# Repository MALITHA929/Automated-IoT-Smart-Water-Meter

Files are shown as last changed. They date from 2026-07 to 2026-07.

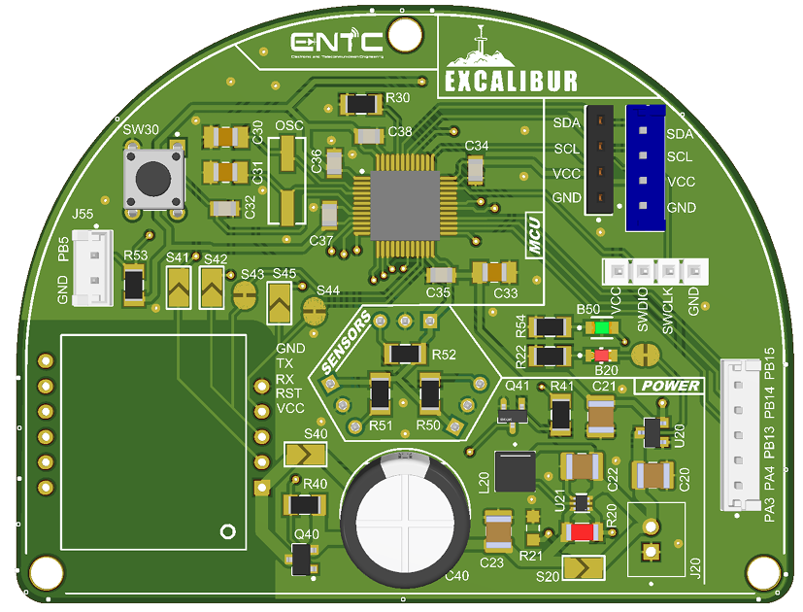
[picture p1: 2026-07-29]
PCB_Image.png

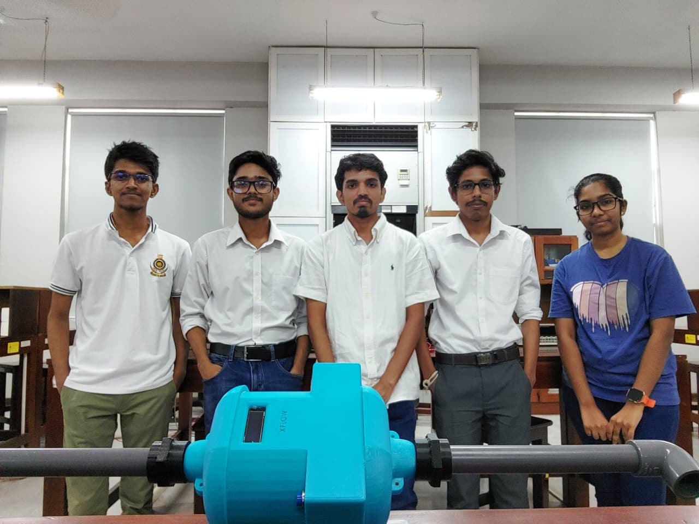
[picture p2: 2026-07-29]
Team_Photo.jpeg

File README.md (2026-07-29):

# 💧 Automated IoT Smart Water Meter

An IoT-enabled smart water metering system designed to modernize residential and utility-scale water management through real-time monitoring, automated billing, leak detection, and cloud-based data analytics. The system integrates a custom embedded hardware platform, GSM communication, cloud infrastructure, and web dashboards to improve billing accuracy, reduce Non-Revenue Water (NRW), and support the digital transformation of Sri Lanka's water distribution network.

---

# 📌 Overview

Traditional mechanical water meters rely on manual meter reading, making them susceptible to inaccurate billing, delayed data collection, water leakage, and high operational costs. Additionally, consumers and water authorities have limited visibility into real-time water consumption, making it difficult to identify leaks and abnormal usage patterns.

The **Automated IoT Smart Water Meter** addresses these challenges by combining low-power embedded hardware, wireless communication, cloud computing, and intuitive web applications into a complete smart metering ecosystem.

The system continuously measures water flow, securely transmits data to the cloud, automatically calculates water consumption, generates billing information, and provides real-time monitoring for both consumers and water utility providers.

---

# 🎯 Objectives

- Develop a low-cost IoT-enabled smart water meter
- Enable real-time water consumption monitoring
- Eliminate manual meter reading
- Automate water billing
- Reduce Non-Revenue Water (NRW)
- Detect leaks and abnormal consumption
- Provide centralized cloud-based monitoring
- Support future smart city infrastructure

---

# 🚰 Problem Statement

Sri Lanka continues to experience significant **Non-Revenue Water (NRW)** losses due to:

- Water leakage
- Manual meter reading
- Meter tampering
- Inaccurate billing
- Delayed data collection
- Lack of real-time monitoring
- High maintenance costs
- Limited consumer visibility

The proposed solution digitizes the entire water metering process while improving operational efficiency for both consumers and water authorities.

---

# 💡 Solution

The proposed system combines:

- Custom Embedded Hardware
- STM32 Low-Power Microcontroller
- Hall-Effect Flow Sensor
- GSM Communication
- Cloud Database
- Administrator Dashboard
- Consumer Web Portal

The smart meter continuously measures water flow, processes consumption locally, transmits data through GSM, stores information securely in the cloud, and presents live analytics through dedicated web dashboards.

---

# ✨ Key Features

## 💧 Smart Water Meter

- Real-time flow measurement
- Cumulative water consumption calculation
- Automated billing
- Leak detection
- Tamper-resistant monitoring
- Low-power operation
- Long battery life
- Remote monitoring

---

## 🌐 Cloud Platform

- Secure cloud database
- Historical data storage
- Live synchronization
- Consumption analytics
- Automated notifications
- REST API integration

---

## 👨‍💼 WaterboardOS (Administrator Dashboard)

- Network-wide monitoring
- Customer management
- Revenue analytics
- Water consumption statistics
- Historical usage trends
- Centralized administration
- Utility monitoring

---

## 👤 AquaSync (Consumer Dashboard)

- Real-time water usage
- Estimated monthly bill
- Historical consumption graphs
- Leak notifications
- Account management
- Previous billing history
- Live synchronization status

---

# ⚙️ Hardware Architecture

## Embedded System

- STM32L071CBT6 (ARM Cortex-M0+)
- SIM800L GSM Module
- Hall-Effect Flow Sensor
- Li-SOCl₂ Battery
- OLED Display
- RTC Crystal
- Low-Power Design

---

## Power Management

- TPS61023 Buck-Boost Converter
- XC6206 3.3V LDO Regulator
- Battery Protection Circuit
- Ultra-Low Power Sleep Mode

---

## Communication

- GSM/GPRS Communication
- HTTP POST Data Transmission
- Cloud Synchronization
- REST API Integration

---

# 🖥️ Software Stack

### Embedded Software

- Embedded C
- STM32CubeIDE
- Low-Power Firmware
- Pulse Counting
- Flow Calculation
- GSM Communication

### Web Technologies

- HTML5
- CSS3
- JavaScript

### Cloud

- Supabase
- REST APIs
- Cloud Database

---

# 📐 PCB Design

The complete hardware platform was designed as a custom **2-layer PCB** using **Altium Designer**.

The PCB includes:

- Power Subsystem
- STM32 MCU Subsystem
- GSM Communication Circuit
- Sensor Interface
- OLED Interface
- SWD Programming Interface
- Expansion GPIO Header

---

# 🛠 Mechanical Design

A custom waterproof enclosure was designed using **SolidWorks** for outdoor deployment.

Features include:

- Waterproof enclosure
- Standard plumbing connectors
- Optimized 9-blade turbine
- Hall sensor mounting
- PCB isolation
- Future expansion support

---

# 🧠 System Workflow

```text
Water Flow
     │
     ▼
Hall-Effect Sensor
     │
     ▼
STM32L0 MCU
     │
Flow Calculation
     │
     ▼
SIM800L GSM Module
     │
     ▼
Cloud Database (Supabase)
     │
     ▼
 ┌───────────────┬────────────────┐
 ▼                               ▼
WaterboardOS               AquaSync
(Admin Dashboard)      (Consumer Dashboard)
```

---

# 🔒 Security

- Secure cloud storage
- Unique meter identification
- Timestamped records
- Role-based authentication
- Secure API communication
- Centralized data management

---

# 📈 Benefits

### Consumers

- Live water usage monitoring
- Accurate billing
- Leak notifications
- Consumption history
- Better water conservation

### Water Utilities

- Reduced Non-Revenue Water
- Automated billing
- Reduced operational costs
- Remote monitoring
- Better maintenance planning
- Revenue analytics

---

# 🚀 Future Improvements

- NB-IoT Connectivity
- LoRaWAN Support
- Remote Valve Control
- AI-Based Leak Prediction
- Smart City Integration
- Mobile Application
- Predictive Maintenance
- Enterprise Cloud Infrastructure

---

# 👥 Team Excalibur

- A.H.T.M. Weerakoon
- K.D. Manatunga
- H.D.J.D. Samaranayaka
- W.M.H. Wanigasundara
- H.W.D. Prabarshana

---

# 👨‍💻 My Contributions

- Mechanical enclosure design using **SolidWorks**
- Electronic component selection
- Hardware integration
- System assembly and soldering
- Prototype testing and validation
- Performance evaluation
- Debugging and hardware verification

---

# 🎓 Academic Project

**Course:** EN2160 – Electronic Design Realization

**Department:** Electronic and Telecommunication Engineering

**University:** University of Moratuwa

---

# 📜 License

This project was developed for academic and research purposes as part of the EN2160 – Electronic Design Realization module at the University of Moratuwa.

---

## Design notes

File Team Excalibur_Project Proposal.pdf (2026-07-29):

# Project Proposal

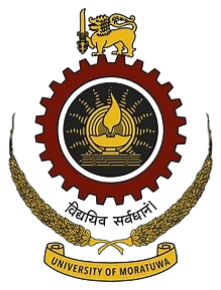
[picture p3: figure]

K.D.Manatunga | 230395T
H.W.D.Prabarshana | 230495B
H.D.J.D.Samaranayake | 230563H
W.M.H.Wanigasundara 230680M A.H.T.M Weerakoon 230689A

## EN-2160 : Engineering Design Realization

### Department of Electronic and Telecommunication Engineering University of Moratuwa

## 1 Problem Statement

### 1.1 Introduction

In Sri Lanka the main sources of water supply to public is provided through sources such as piped water, public taps, tube wells, protected wells, semi protected wells, rural water supply projects, bottled water Then in case of pipe water distribution the main body that is responsible for that is National Water Supply and Drainage Board(NWSDB). About 75% of urban population and about 40% of the rural population are supplied water through this distribution newtorks. Main resoviours for them are tube wells and surfae water resoviours( eg. lakes, rivers etc)
Currently, meters are placed at the households or more generally at the user end to monitor the amount of usage for management purposes such as billing.

### 1.2 Current difficulties

- Manual measurement taking
The main thing we observe here is that water meter monitoring is something that has the potential to move towards automated monitoring to improve the quality of service by minimizing the errors occur and minimizing the costs by reducing the human interactions.
- Real-time monitoring and accessing usage history
In the current system, there is a lack of accessability to realtime data and to see the usage history. The only method that is possible right now is to look it from the meter directly or get annual data from the bill.

## 2 Proposed Solution

### 2.1 Introduction

We thought through the problem and decided to introduce an integrated device with a smart meter and a smart ball-valve.

### 2.2 Functionality

Here, using our proposed device we intend to let user access real-tine water usage and to make it convenient to analyze past data by providing an application for better user experience. In addition to that from the side of the water board we can illuminate the necessity of checking the meters by visiting house holds.

### 2.3 Existing products

In the market we can find the smart meter and the ball valve separately only in the international market. If someone to import them that will cost a huge amount considering all the expenditures with taxes and all.

### 2.4 Stake-holders

Some of the stake-holders that we identified regarding our project are,

- House-holds
- Farmers
- Water-board

2

### Resources

### - https://www.statistics.gov.lk/Resource/en/Health/DemographicAndHealthSurveyReport-

### 2016-Chapter2.pdf

### - https://drive.google.com/file/d/1m3dZbix2ck5f2yChTXGhR04r8Bdc5cNK/view

3

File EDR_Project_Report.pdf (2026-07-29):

# Automated IoT Smart Water Meter

# Project Report

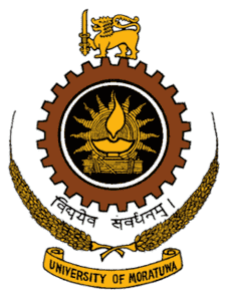
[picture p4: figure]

### TEAM EXCALIBUR

230395T | K.D. Manatunga
230563H | H.D.J.D.Samaranayaka
230680M | W.M.H.Wanigasundara
230689A | A.H.T.M.Weerakoon
230495B | H.W.D.Prabarshana

## EN2160 - Electronic Design Realization

### Department of Electronic and Telecommunication Engineering

### University of Moratuwa

### July 20, 2026

## CONTENTS

1 Problem Statement | 4
2 Objectives | 5
3 Survey & Market Validation | 6
4 Stakeholder and Needs Analysis | 10
5 Proposed Solution and Core Mechanism | 11
6 Hardware Architecture | 13
7 PCB Design and Schematic Architecture | 15
8 Software and Dashboard | 22
9 Mechanical Enclosure Design | 24
10 Cost Estimation and Production Scope | 26

Automated IoT Smart Water Meter | Project Report
11 Team Contributions | 28
12 Conclusion | 29

## 1 Problem Statement

Sri Lanka’s water supply network continues to experience significant Non-Revenue Water (NRW)

losses, resulting in substantial financial losses, operational inefficiencies, and reduced water

availability for consumers. NRW refers to treated water that is produced but not billed due

to physical leaks, unauthorized consumption, inaccurate metering, or administrative errors.

According to the National Water Supply and Drainage Board (NWSDB), the national NRW

level remains approximately 24.8, while the Auditor General’s report estimates losses of nearly

27. It is estimated that every 1% reduction in NRW could save approximately Rs. 790 million

annually, demonstrating the significant economic impact of improving water management.

Traditional mechanical water metering systems rely heavily on manual meter reading, mak-

ing the billing process susceptible to human error, estimated readings, delayed data collection,

and meter tampering. Furthermore, consumers and water authorities lack real-time visibility

into water consumption, preventing the early identification of abnormal usage patterns and

leakage.

Another major limitation of the current system is the absence of remote monitoring and

control capabilities. Water utilities must physically dispatch maintenance crews to inspect

meters, investigate leaks, or disconnect water supplies for maintenance or unpaid bills. This

process is time-consuming, labour-intensive, and increases operational costs.

Maintenance expenses associated with aging mechanical water meters also place a consider-

able financial burden on utilities. A JICA pilot study conducted in the Harispattuwa Division

reported an 8.37% defective meter rate and approximately Rs. 7.9 million spent on repairs,

illustrating the high maintenance requirements of conventional metering infrastructure.

These challenges highlight the need for a modern, intelligent, and cost-effective smart water

metering solution capable of providing real-time monitoring, automated billing, leak detec-

tion, remote communication, and cloud-based data management. Such a system would reduce

NRW, improve billing accuracy, lower operational costs, and enhance customer service while

supporting the digital transformation of Sri Lanka’s water distribution network.

## 2 Objectives

The primary objective of this project is to design and develop a low-cost, IoT-enabled smart

water metering system capable of improving the efficiency, accuracy, and reliability of water

distribution and billing. The specific objectives are:

- Design and develop a low-cost, battery-powered IoT smart water meter suitable for res-

idential water distribution systems providing an expected operational lifetime of more

than 10 years under normal operating conditions.

- Enable real-time remote transmission of water flow rate and cumulative consumption data

to a centralized cloud database using GSM communication.

- Automate the water billing process using accurate, tamper-resistant consumption mea-

surements, thereby eliminating manual meter reading.

- Develop web-based dashboards for both utility administrators and consumers to monitor

live water consumption, billing information, revenue statistics, and network-wide analyt-

ics.

- Support the reduction of NRW through continuous flow monitoring, leak detection, and

anomaly identification based on real-time consumption patterns.

## 3 Survey & Market Validation

To validate the problem and gauge demand for a smart metering solution, the team conducted

a survey targeting household water users. The results reinforce the core assumptions behind

this proposal: water wastage is common, manual management remains the norm, and there is

strong demand for real-time, remote monitoring.

### 3.1 Current Water Supply Management

Q1 — How do you currently manage your water supply?

A significant proportion of respondents still rely on manual methods for managing their

water supply. Around 45.5% use a manual valve, while 31.8% operate a manually-switched

electric pump. Together, over three-quarters of respondents currently have no automated or

remote control over their household water supply.

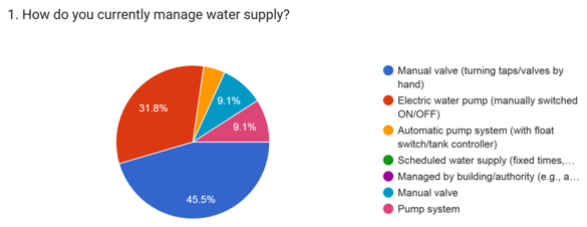
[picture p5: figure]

Figure 1: Current methods used by households to manage water supply

### 3.2 Household Water Wastage Issues

Q2 — Do you face water wastage issues?

The survey revealed that water wastage is a widespread issue, with 72.7% of respondents

reporting that they experience water wastage problems in their households.

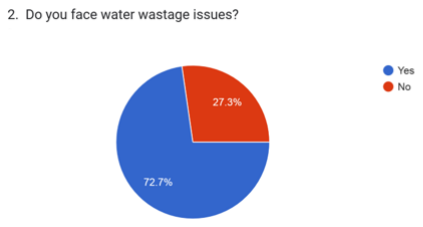
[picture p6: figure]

Figure 2: Percentage of households experiencing water wastage issues

Q3 — If yes, what kind of issues?

Among respondents who experienced water wastage, forgetting to turn off water was iden-

tified as the primary cause, accounting for 47.1% of responses. Leakage was the second most

common issue (23.5%), followed by overuse (17.6%). These issues can be directly addressed

through the proposed system using remote shutoff capability and automated leakage alerts.

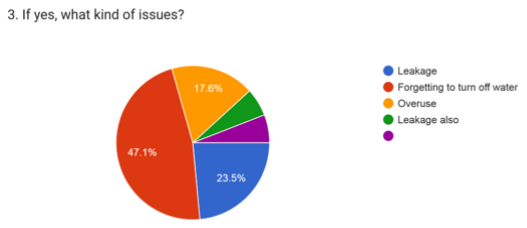
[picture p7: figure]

Figure 3: Main causes of household water wastage

### 3.3 Demand for Real-Time Monitoring

Q5 — Would you like to monitor water usage in real time?

The survey demonstrated strong demand for real-time monitoring, with 90.9% of respon-

dents expressing interest in monitoring their household water consumption. This directly vali-

dates the core value proposition of the AquaSync consumer application.

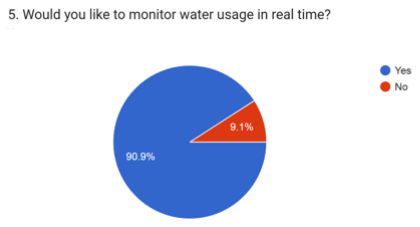
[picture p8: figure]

Figure 4: User interest in real-time water usage monitoring

### 3.4 Perceived Usefulness of the System

Q6 — How useful would this system be for you?

The proposed smart water metering system received highly positive feedback. Approxi-

mately 95% of respondents rated the system as either “very useful” (approximately 50%) or

“useful” (approximately 45%), indicating strong user acceptance.

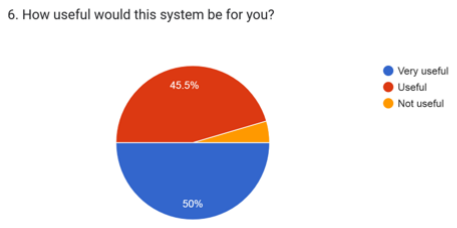
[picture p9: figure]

Figure 5: User perception of the usefulness of the proposed system

### 3.5 Preferred Features

Q7 — Which features do you prefer?

Leak detection alerts were the most requested feature, selected by 68.2% of respondents.

Monthly usage reports and real-time water usage monitoring were preferred by 63.6% and 59.1%

of respondents, respectively. Furthermore, remote ON/OFF valve control and automatic shutoff

features were valued by 54.5% of respondents each.

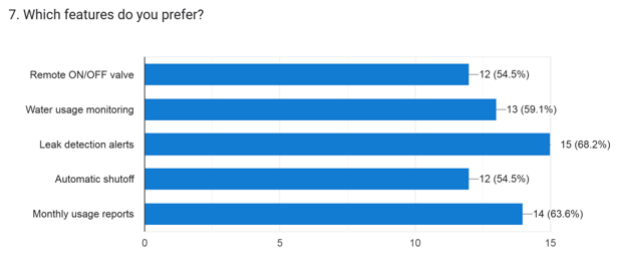
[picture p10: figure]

Figure 6: Preferred features of the smart water metering system

### 3.6 Customer Willingness to Pay

Q8 — Would you be willing to pay for such a system? (22 responses)

Approximately 73% of respondents indicated that they would be willing to pay for the

proposed smart water metering system. This result provides evidence of commercial viability

and suggests that the solution has potential beyond a purely utility-driven deployment.

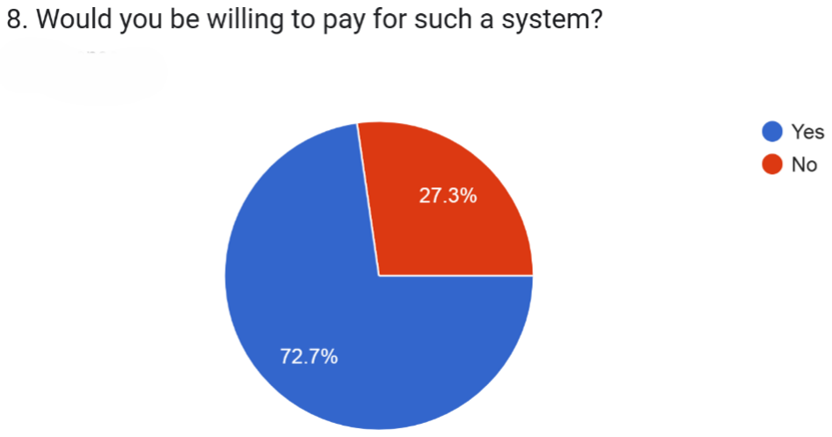
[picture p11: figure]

Figure 7: Customer willingness to pay for the proposed system

## 4 Stakeholder and Needs Analysis

The proposed Automated IoT Smart Water Meter is intended to benefit multiple stakeholders

by addressing their specific operational and service requirements.

Table 1: Stakeholder and Needs Analysis

Stakeholder | Key Needs
NWSDB / Utility | • Real-time monitoring of NRW • Automated leak detection and anomaly identifica-tion • Accurate and tamper-resistant billing data • Reduced operation and maintenance (O&M) costs
Consumers / House-holds | • Transparent visibility of water consumption • Accurate and dispute-free billing • Mobile access to real-time consumption data • Notifications for remote disconnection and abnor-mal usage
Government / Regula-tors | • Achievement of national NRW reduction targets • Availability of auditable metering and billing records • Reduced public subsidy burden • Alignment with Sustainable Development Goal (SDG) 6 for clean water and sanitation

## 5 Proposed Solution and Core Mechanism

The proposed Automated IoT Smart Water Meter provides an end-to-end solution for intelligent

water consumption monitoring, automated billing, and NRW reduction. The system integrates

flow sensing, embedded processing, wireless communication, cloud storage, and a web-based

dashboard into a single IoT platform. The overall operation of the system is summarized

below.

- Flow Sensing: A water flow sensor containing a rotor with an embedded permanent

magnet generates electrical pulses as water passes through the pipe. A Hall-effect sensor

detects these pulses, where the pulse frequency is directly proportional to the instanta-

neous water flow rate.

- Microcontroller Processing: An STM32L0 ultra-low-power microcontroller counts the

incoming pulses and computes the instantaneous flow rate and cumulative water volume

using the sensor calibration factor.

- GSM Communication: A SIM800L GSM module periodically transmits the measured

data to the cloud using HTTP POST requests over the cellular network, enabling remote

monitoring without requiring local Wi-Fi infrastructure.

- Cloud Backend: A Supabase cloud database stores each meter reading together with the

corresponding meter identification number and timestamp, ensuring secure data storage,

traceability, and auditability.

- Billing and User Dashboard: A web-based consumer dashboard retrieves the stored

data to provide real-time consumption visualization, estimated billing, historical usage

analysis, and leak notifications for both consumers and utility administrators.

### 5.1 Key Features

The proposed system offers several features that improve the efficiency, reliability, and usability

of conventional water metering systems.

- Real-Time Monitoring: Live flow rate and cumulative consumption data are trans-

mitted to the cloud via GSM, eliminating the need for manual meter reading.

- Automated Billing: Water bills are generated automatically using accurate and tamper-

resistant consumption records stored in the cloud database.

- Battery-Powered Operation: The device is powered by high-energy-density Li-SOCl2

primary batteries, enabling long-term standalone operation without connection to the

electrical grid.

- NRW Detection: Continuous flow monitoring allows the detection of abnormal con-

sumption patterns and potential leaks, helping utilities reduce NRW.

- Cloud-Based Data Management: All meter readings are securely stored in a central-

ized cloud database, enabling historical analysis, auditing, and remote access.

- Consumer Dashboard: A user-friendly web application allows consumers to monitor

water usage, track estimated bills, view historical consumption trends, and receive noti-

fications of abnormal water usage.

## 6 Hardware Architecture

The proposed smart water meter is built using low-power embedded hardware components

selected to maximize battery life, reliability, and communication capability while minimizing

deployment and maintenance costs.

Table 2: Hardware Architecture

Component | Role | Specification
STM32L0 MCU | Microcontroller | 32-bit ARM Cortex-M0+ running at 32 MHz, 64 KB Flash, 8 KB SRAM, I²C, SPI, UART, LPUART and LPTIM peripherals, compatible with STM32CubeIDE and Arduino framework.
SIM800L GSM Module | Communication | Quad-band GSM/GPRS communication mod-ule supporting AT commands, HTTP POST requests to the cloud backend, and ultra-low-power sleep mode.
Li-SOCl2 Battery | Power Supply | 3.6 V primary (non-rechargeable) lithium-thionyl chloride battery with ultra-low self-discharge (<1% per year), optimized for low-power duty-cycled operation and an expected operational lifespan exceeding 10 years.
Hall-Effect Flow Sensor | Flow Sensing | Rotor-mounted permanent magnet and Hall-effect sensor producing pulses proportional to water flow, enabling accurate measurement of instantaneous flow rate and cumulative water volume without additional sensing hardware.

### 6.1 Alternatives Considered

Several alternative hardware solutions were evaluated during the design process before selecting

the final system architecture.

- Li-ion Battery (3.6–4.2 V, 1500–3600 mAh): Rejected in favor of the Li-SOCl2 bat-

tery due to its significantly longer service life, lower self-discharge rate, and maintenance-

free operation suitable for sealed outdoor installations.

- ATmega328P Microcontroller (16 MHz, 32 KB Flash, 2 KB SRAM): Rejected

because the STM32L0 provides substantially lower power consumption, greater processing

capability, larger memory, and a richer set of peripherals while operating at 3.3 V.

- Solar Power Supply (5 V, 200 mA): Considered as an alternative power source but

rejected because underground or enclosed water meter installations often lack reliable

sunlight, reducing system availability and increasing installation complexity.

### 6.2 Power Consumption and Battery Life Estimation

To validate the system’s capacity for long-term standalone operation, a theoretical battery life

estimation was conducted. The microcontroller alternates between an ultra-low-power sleep

state (waking only for RTC and sensor interrupts) and an active transmission state where the

SIM800L GSM module connects to the network.

The time-weighted average current consumption, Iavg, over a standard 1-hour (3,600 s)

reporting cycle is calculated using the following formula:

Iavg =

(Itx × ttx) + (Isleep × tsleep)

Tcycle

(1)

Based on component specifications and transmission timing:

- Transmission State: Itx = 250 mA for a duration of ttx = 10 s
- Sleep State: Isleep = 1.5 µA = 0.0015 mA
- Sleep Time: tsleep = 3, 600 − 10 = 3, 590 s

Substituting these values yields:

Iavg =

(250 × 10) + (0.0015 × 3590) 3600

=

2500 + 5.385
3600
≈ 0.696 mA | (2)

The system is powered by a 19,000 mAh Li-SOCl2 primary battery. Assuming a conservative

85% usable capacity (16,150 mAh) to account for voltage drops and temperature fluctuations,

the expected lifespan under an hourly GSM transmission cycle is:

Lifespan = | 16, 150 mAh
0.696 mA × 24 h/day × 365 days/year
≈ 2.65 years | (3)

Note: While hourly transmission yields a lifespan of approximately 2.65 years, the opera-

tional objective of 10+ years can be achieved by adjusting the firmware duty cycle to transmit data daily rather than hourly, drastically reducing the GSM module’s active time.

## 7 PCB Design and Schematic Architecture

### 7.1 Top-level schematic hierarchy

The PCB was designed using Altium Designer with a hierarchical architecture to improve mod-

ularity, readability, and ease of verification. The top-level schematic references four functional

sub-sheets: Power, Microcontroller (MCU), Communication, and Peripherals. These

sheets are interconnected using labeled ports such as GSM ON/OFF, USART1, TIM2 channels, and

I2C1, allowing each subsystem to be developed, tested, and verified independently while main-

taining a clean overall design.

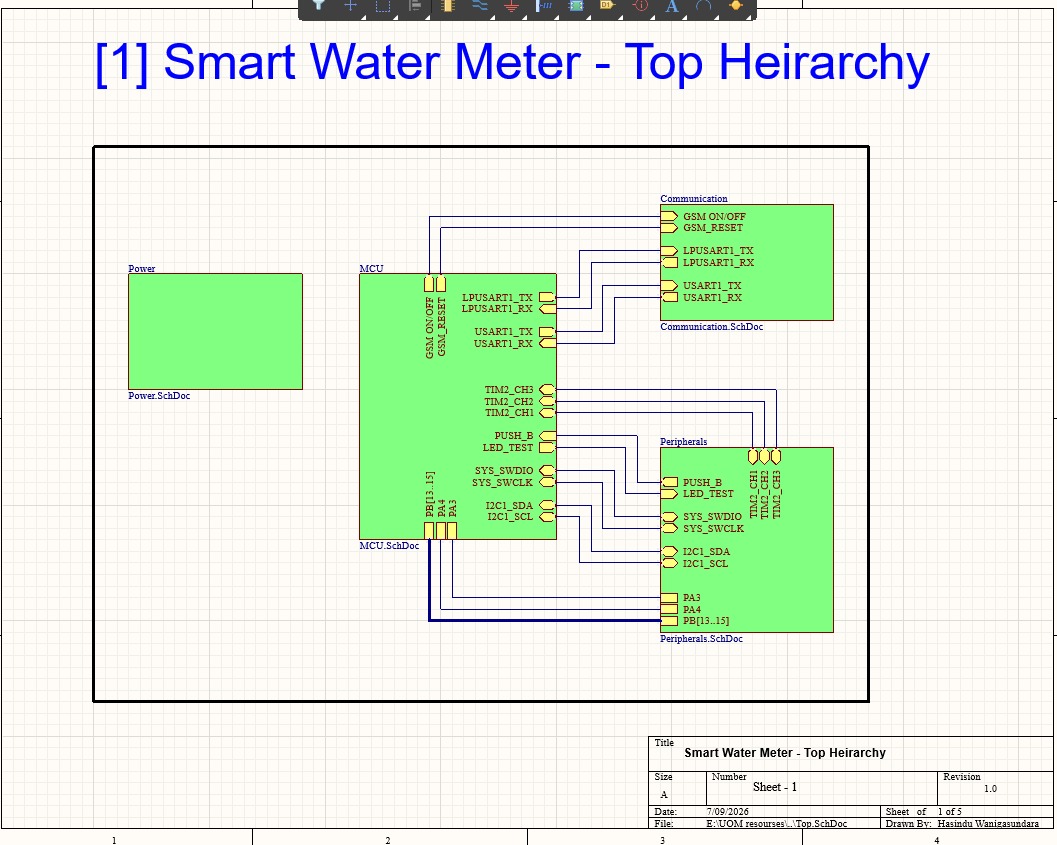
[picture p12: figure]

Figure 8: Top-level schematic hierarchy showing the Power, MCU, Communication, and Peripherals sheets.

### 7.2 Power Subsystem

The power subsystem generates two regulated supply rails from the battery source to satisfy

the different voltage requirements of the system components.

- 3.3 V LDO Regulator (XC6206P332MR): Supplies the STM32L0 microcontroller

and other low-power peripherals from the battery voltage. The regulator is stabilized

using 22 µF input and output filter capacitors.

- 4 V Buck–Boost Converter (TPS61023DRLR): Generates a stable 4 V supply for

the SIM800L GSM module using a 2.2 µH inductor and a resistive feedback network to

set the output voltage.

The output voltage of the TPS61023 buck–boost converter is determined by the external

feedback resistor divider according to

VOUT = VREF
1 +

RTOP

RBOTTOM

where the internal reference voltage is VREF = 0.6 V.

Using

RTOP = 68 kΩ, RBOTTOM = 12 kΩ,

the output voltage is

VOUT = 0.6

1 +

68

12
= 0.6
80

12
= 4.0 V.

Therefore, the feedback resistor network is designed to produce a regulated output voltage

of 4.0 V, which supplies the SIM800L GSM module.

- Battery Connector (J20): Provides the battery interface and includes a status LED

with a current-limiting resistor together with a Schottky diode for reverse-polarity pro-

tection.

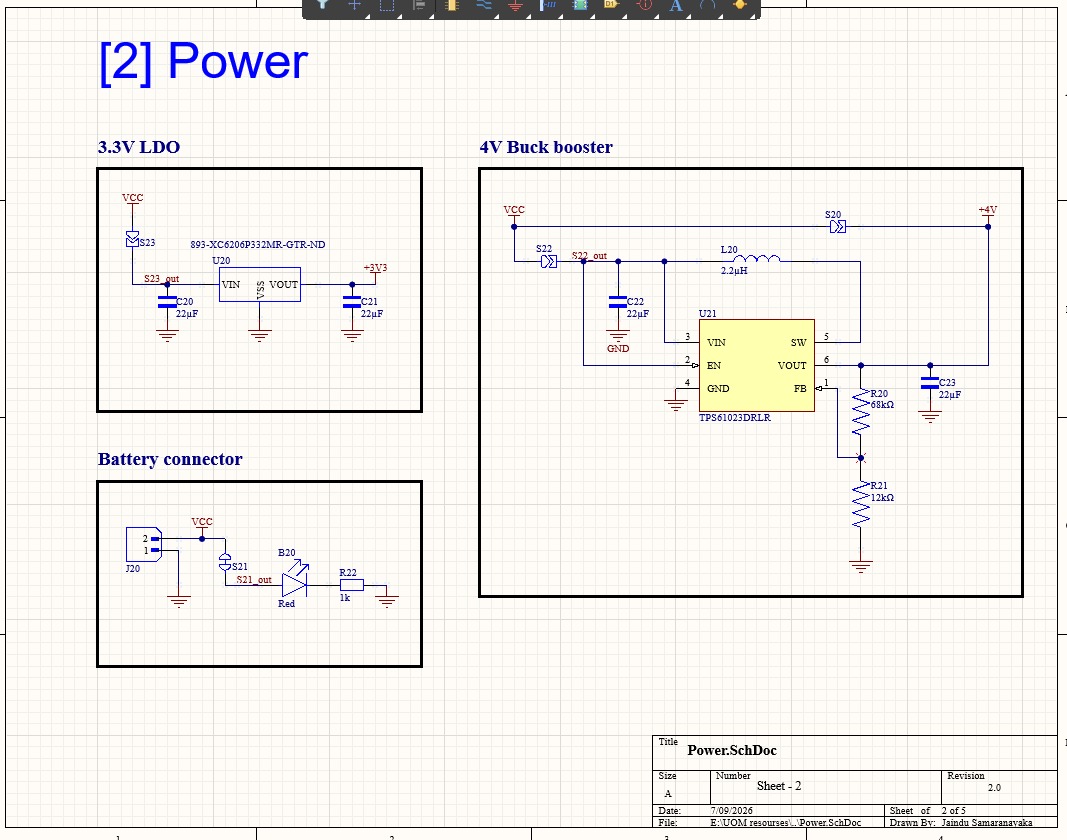
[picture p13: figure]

Figure 9: Power subsystem showing the 3.3 V LDO regulator, 4 V buck–boost converter, and battery interface.

### 7.3 Microcontroller (MCU)

The STM32L071CBT6, based on the ARM Cortex-M0+ architecture, serves as the central

controller of the smart water meter. It interfaces with all system modules through dedicated

communication and peripheral interfaces.

Major interfaces include:

- TIM2 input capture channels for Hall-effect sensor pulse counting.
- USART1 and LPUART1 for GSM communication.
- I
2C1 interface for the OLED display.
- Serial Wire Debug (SWD) interface for firmware programming and debugging.
- General-purpose I/O for the push button, status LED, and GSM power-control signals.

To ensure stable operation during low-power modes, the MCU is supported by multiple de-

coupling capacitors (C33–C38) and a 32.768 kHz crystal oscillator (OSC30) with load capacitors

C30 and C31 for the real-time clock (RTC).

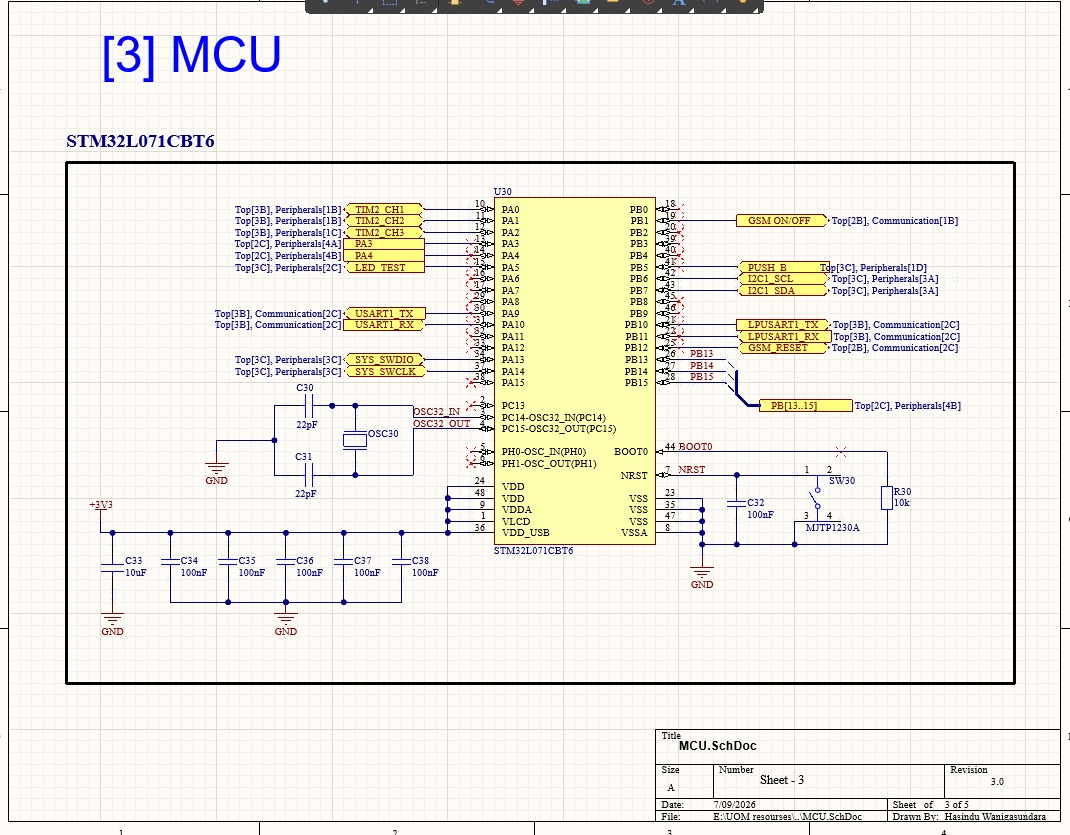
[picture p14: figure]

Figure 10: Microcontroller subsystem featuring the STM32L071CBT6 with SWD, USART, TIM2, and I²C interfaces.

### 7.4 Communication Subsystem

Wireless communication is provided by the SIM800L quad-band GSM module, enabling periodic

transmission of water consumption data to the cloud.

To minimize energy consumption, the GSM module is powered only during transmission

cycles. An AO3401A P-channel MOSFET (Q40), controlled through an MMBT3904 NPN

transistor (Q41), allows the STM32L0 to completely disconnect power from the GSM module

when it is idle.

A 4700 µF bulk capacitor (C40) supplies the high peak currents required during GSM

transmission bursts, while Schottky diodes on the RX, TX, and RESET lines protect the

MCU’s 3.3 V logic from higher voltage levels generated by the communication module.

### 7.5 Peripheral Subsystem

The peripheral subsystem integrates all external interfaces required for sensing, user interaction,

programming, and future expansion.

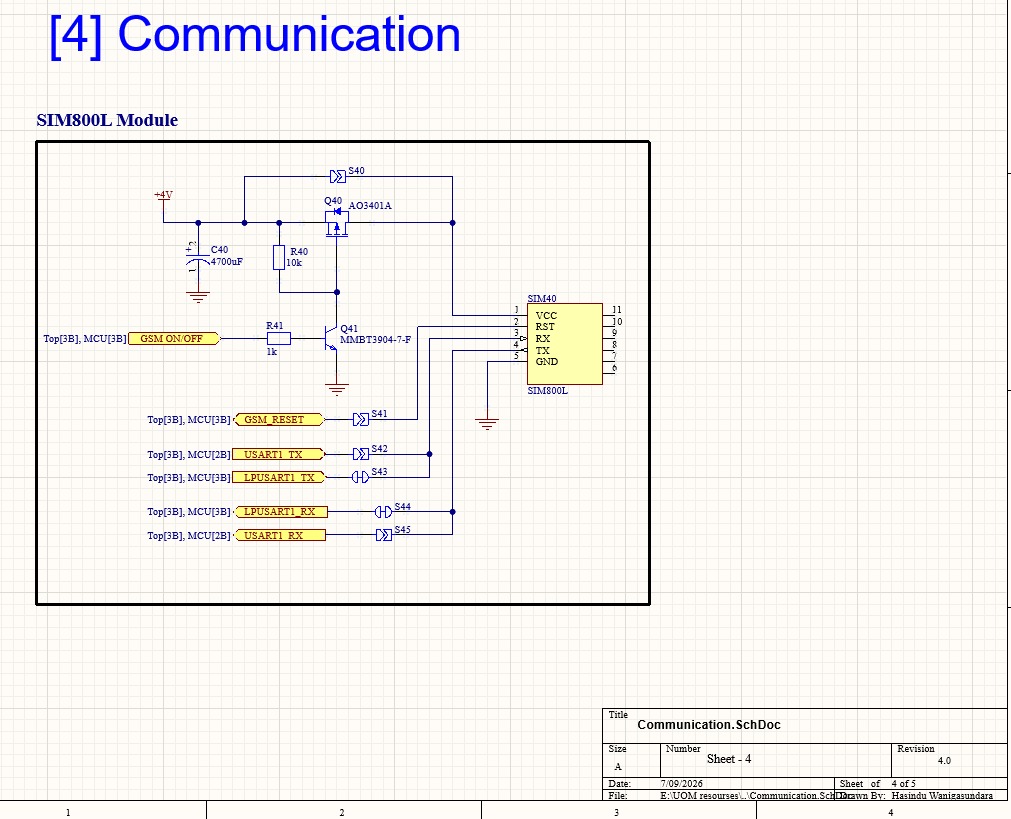
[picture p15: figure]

Figure 11: Communication subsystem showing the SIM800L GSM module with switched power control and logic-level protection.

- Hall-effect Sensors: Three Hall-effect sensor inputs connected to TIM2 CH1–CH3

through B3B-EH JST connectors, each including a 10 kΩ pull-up resistor and local de-

coupling capacitor.

- OLED Display: Connected through the I²C1 interface and exposed using both a JST

connector and a pin header for displaying system status and water consumption.

- ST-Link Programming Interface: Dedicated four-pin SWD connector providing firmware

programming and debugging capability.

- User Interface: A green status LED (B50) and a push button provide local diagnostics

and manual system interaction.

- Expansion Header: Additional GPIO pins (PA3, PA4, PB13–PB15) are made available

for future hardware extensions such as additional sensors or communication modules.

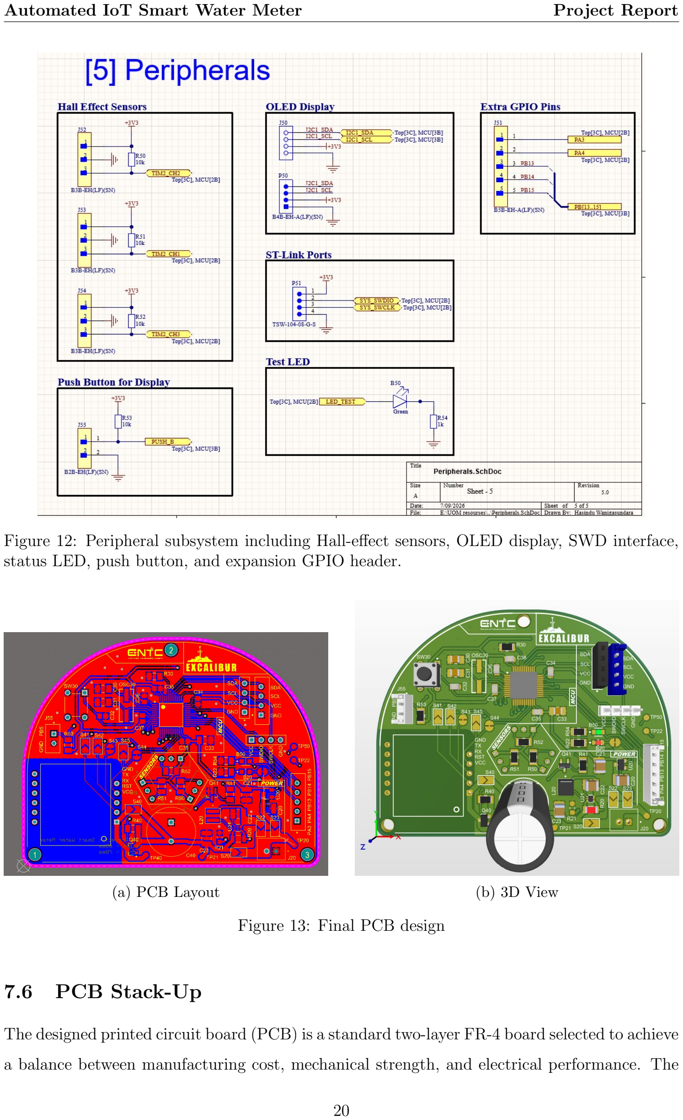
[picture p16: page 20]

Figure 12: Peripheral subsystem including Hall-effect sensors, OLED display, SWD interface, status LED, push button, and expansion GPIO header.

(a) PCB Layout | (b) 3D View

Figure 13: Final PCB design

### 7.6 PCB Stack-Up

The designed printed circuit board (PCB) is a standard two-layer FR-4 board selected to achieve

a balance between manufacturing cost, mechanical strength, and electrical performance. The overall board thickness is 1.59 mm, consisting of a 1.50 mm FR-4 dielectric core and 40 µm

copper layers on both the top and bottom sides. Solder mask and silkscreen layers are applied

to provide electrical insulation, environmental protection, and component identification.

The top copper layer is primarily used for signal routing and component placement, while

the bottom copper layer is utilized for additional signal routing and the ground return paths.

The FR-4 dielectric provides electrical isolation between the copper layers while maintaining

adequate mechanical rigidity for field deployment.

The complete PCB layer stack-up is illustrated in Figure 14.

Table 3: PCB Layer Stack-Up

Layer | Material | Thickness | Purpose
Top Overlay | Silkscreen | – | Component labels
Top Solder Mask | Solder Resist | 0.01 mm | Copper protection
Top Copper | Copper | 0.04 mm | Signal routing
Core | FR-4 Dielectric | 1.50 mm | Electrical insulation
Bottom Copper | Copper | 0.04 mm | Signal routing and GND
Bottom Solder Mask | Solder Resist | 0.01 mm | Copper protection
Bottom Overlay | Silkscreen | – | Component labels

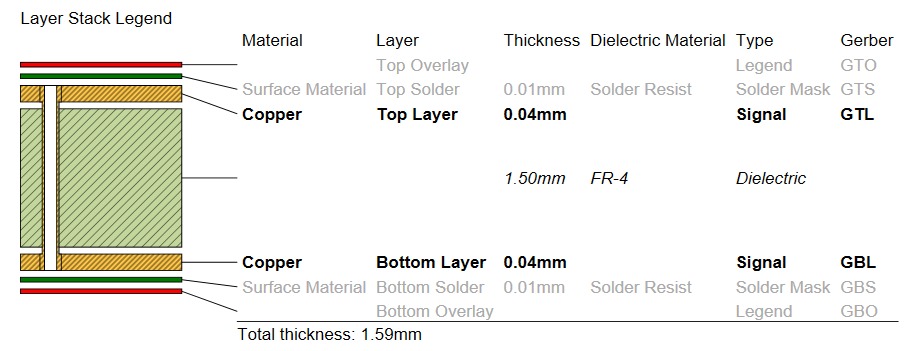
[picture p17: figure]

Figure 14: Layer stack-up of the designed two-layer PCB.

## 8 Software and Dashboard

To complement the smart water meter hardware, two web-based software platforms were de-

veloped: WaterboardOS for utility administrators and AquaSync for consumers. Together,

these platforms provide real-time monitoring, automated billing, data visualization, and cen-

tralized system management.

### 8.1 WaterboardOS (Administrator Dashboard)

WaterboardOS is a centralized web dashboard designed for water utility administrators. The

portal can be accessed at: https://waterboard-management-system-git-main-aqua-sync-excalibur.

vercel.app/login. (https://waterboard-management-system-git-main-aqua-sync-excalibur.vercel.app/login) It provides comprehensive monitoring and management tools for the entire

water distribution network.

- System-wide Analytics: Displays real-time statistics of the total water consumed

across the distribution network.

- Revenue Monitoring: Provides live tracking of total revenue generated from customer

billing.

- Client Overview: Displays the total number of active customers connected to the sys-

tem.

- Historical Trends: Visualizes water consumption over the previous 30 days, enabling

administrators to identify usage patterns and detect anomalies.

- Centralized Management: Provides tools for customer management, notification han-

dling, system configuration, and administrative control.

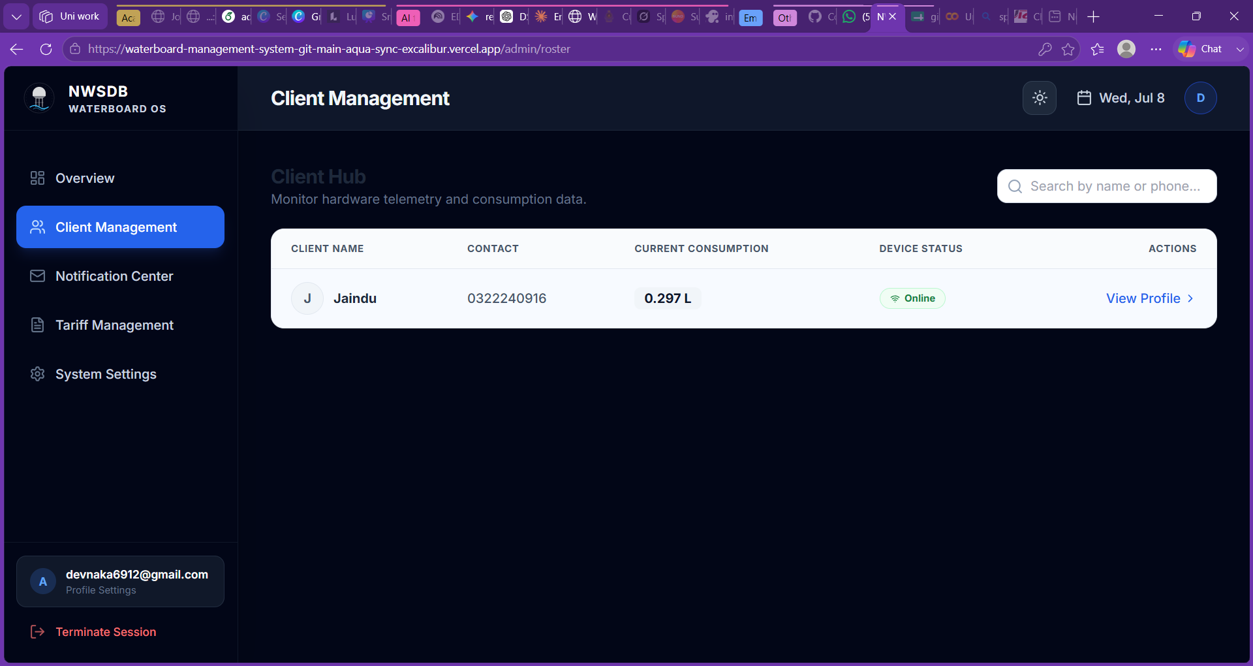
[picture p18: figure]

(a) Login Page | (b) Client Dashboard | (c) Admin Dashboard

Figure 15: Web interfaces developed for the Automated IoT Smart Water Meter system.

### 8.2 AquaSync (Consumer Web Application)

AquaSync is a consumer-facing web application that enables users to monitor their water usage

and billing information in real time. The web application can be securely accessed at: https:

//waterboard-management-system-git-main-aqua-sync-excalibur.vercel.app/login.

- Personal Usage Tracking: Displays the total volume of water consumed during the

current billing cycle.

- Live Bill Estimation: Calculates and updates the estimated water bill continuously

based on current consumption.

- Consumption History: Presents daily water consumption through interactive graphs

for improved usage awareness.

- Live Synchronization Status: Indicates the communication status between the smart

meter and the cloud, ensuring users receive up-to-date information.

- Account Management: Allows users to review previous bills, update profile informa-

tion, and manage account settings.

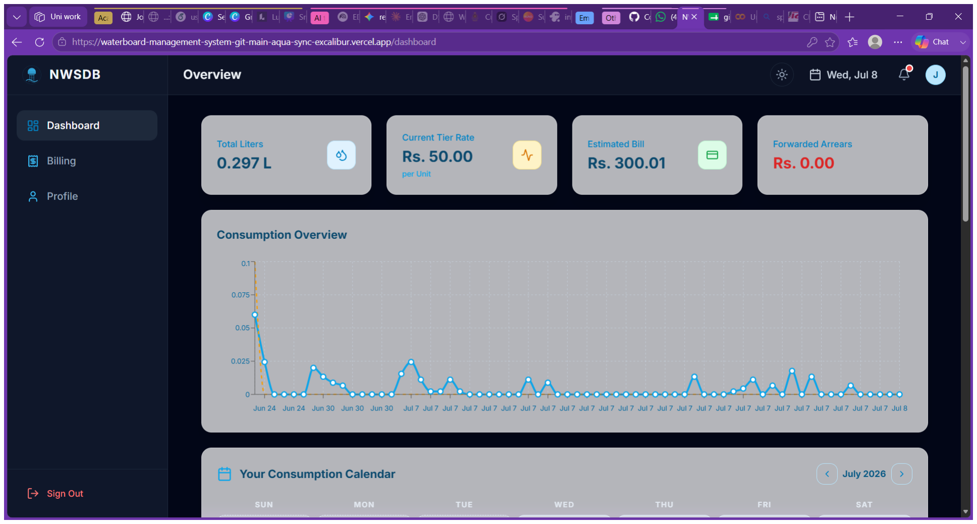
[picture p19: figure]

Figure 16: Client dashboard interface

## 9 Mechanical Enclosure Design

The mechanical enclosure was designed to provide a compact, durable, and waterproof housing

while ensuring accurate flow measurement and ease of installation within existing municipal

water distribution systems. The enclosure integrates the flow sensor, electronics, and plumbing

interfaces into a single robust assembly.

- Standardized Plumbing Integration: Threaded inlet and outlet ports enable direct,

leak-proof connection to existing municipal water pipelines without requiring specialized

adapters.

- Precision Nine-Blade Turbine:

To optimize the automated smart water meter for high-precision utility billing and long-

term durability, the physical rotor was designed with exactly N = 9 blades. The en-

gineering justifications for selecting 9 blades over other configurations are summarized

below:

– Elimination of Resonance (Odd vs. Even): Even-numbered blade configu-

rations (2, 4, 6, 8) cause opposing blades to pass the high-pressure inlet and outlet

ports at the exact same instant. This creates symmetric pressure pulses that induce

physical vibration, acoustic noise, and premature bearing wear. An odd 9-blade

geometry structurally breaks this rotational symmetry, distributing hydrodynamic

forces smoothly across the rotation cycle and extending the meter’s mechanical lifes-

pan.

– Maximizing Low-Flow Sensitivity: Compared to an 8-blade rotor, a 9-blade

design increases the physical pulse density by 12.5% per physical revolution. The

volumetric flow rate Q is mathematically related to the generated pulse frequency f

by:

Q =

f
K

(4)

Where K is the meter calibration factor (pulses per unit volume). The pulse fre-

quency f is defined as:

f = N · n | (5)

Where N = 9 is the blade count, and n is the rotational speed of the turbine.

Increasing N to 9 provides the STM32L0 microcontroller with a higher sampling resolution, allowing the system to detect minor leaks and low-flow trickles that would

otherwise slip through lower blade counts undetected.

– High Startup Torque: Lower blade counts (2 to 5) feature wide angular gaps

that allow water to bypass the turbine without spinning it. The smaller 40◦ angular

pitch of a 9-blade rotor maximizes hydrodynamic force transfer, allowing the rotor

to overcome static bearing friction and begin spinning at minimal flow rates.

– Prevention of Flow Restriction (N > 9): While increasing the blade count

beyond 9 would theoretically increase resolution, it would excessively restrict the

physical flow channel, increase hydrodynamic drag (resulting in a higher system

pressure drop), and complicate the injection molding process of the physical rotor.

- Hydrodynamic Cylindrical Chamber: The internal flow chamber is optimized to

minimize turbulence and pressure loss, improving measurement accuracy while maintain-

ing smooth water flow through the meter.

- Isolated Sensor Mounting: A waterproof lid secured by four screw bosses isolates

the printed circuit board (PCB) and Hall-effect sensors from direct water exposure while

maintaining precise alignment with the turbine magnet.

- Quadrature-Encoding Ready: The enclosure provides sufficient space for a future

dual Hall-effect sensor configuration, enabling quadrature encoding for enhanced flow

measurement accuracy and reverse-flow tamper detection.

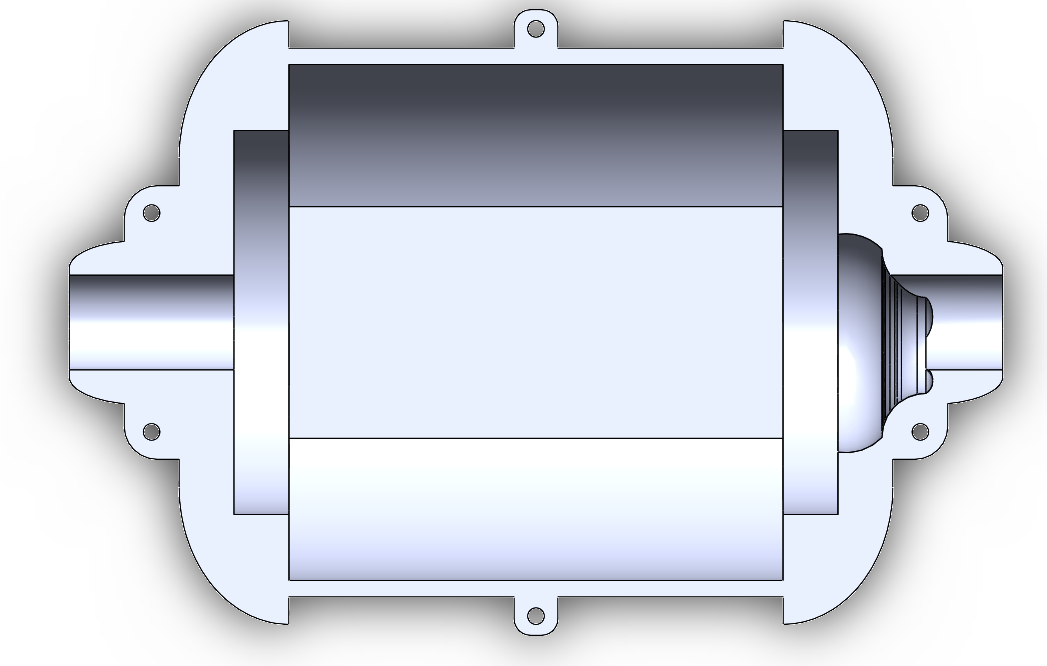
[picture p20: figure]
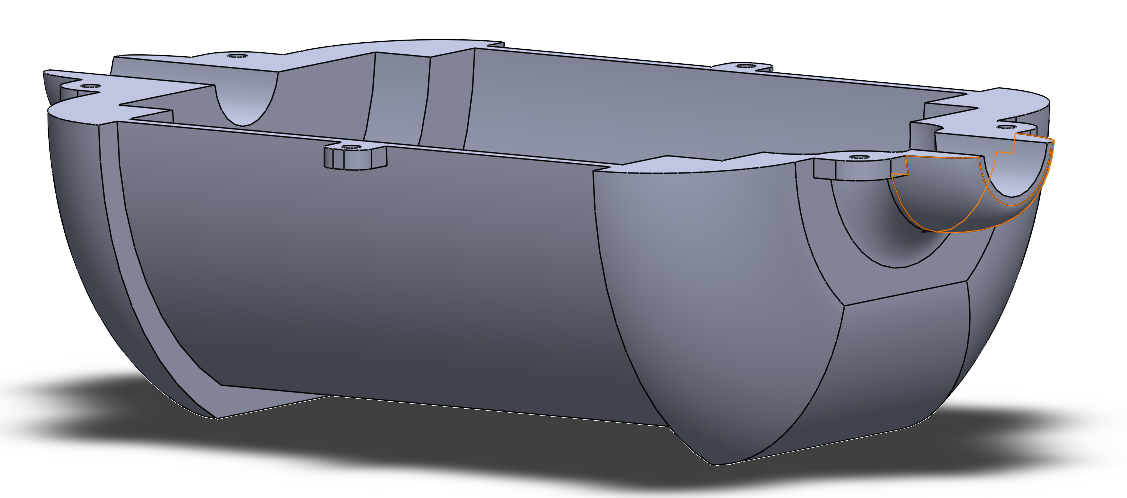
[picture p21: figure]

Figure 17: Top and side views of the water meter cover.

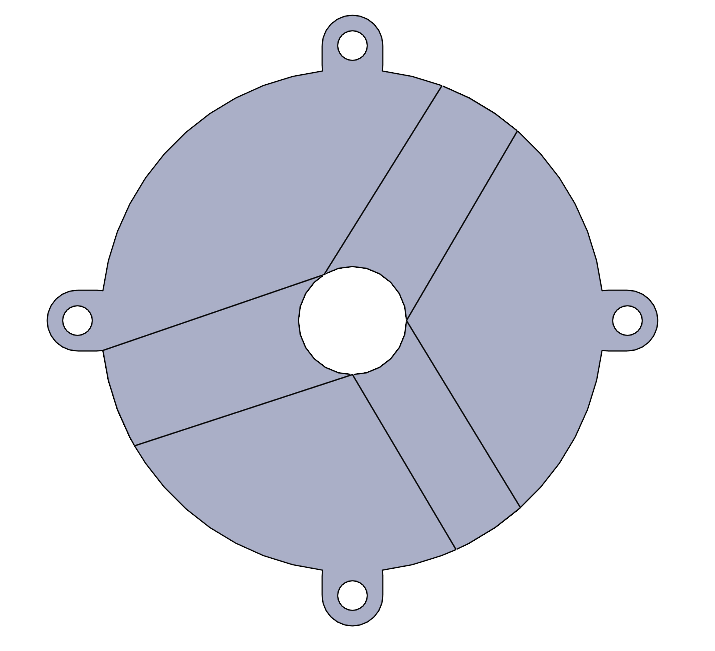
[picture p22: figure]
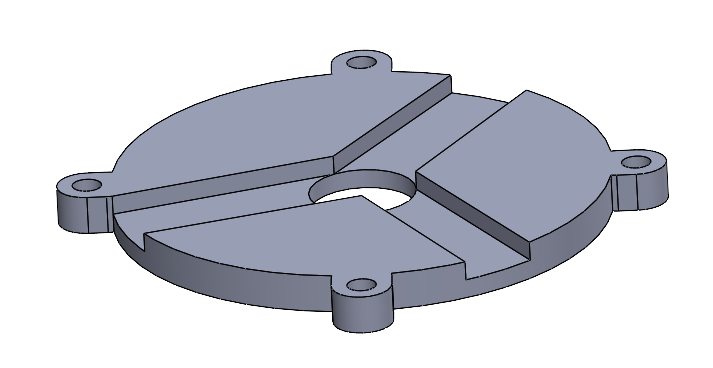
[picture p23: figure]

Figure 18: Top and side views of the top lid

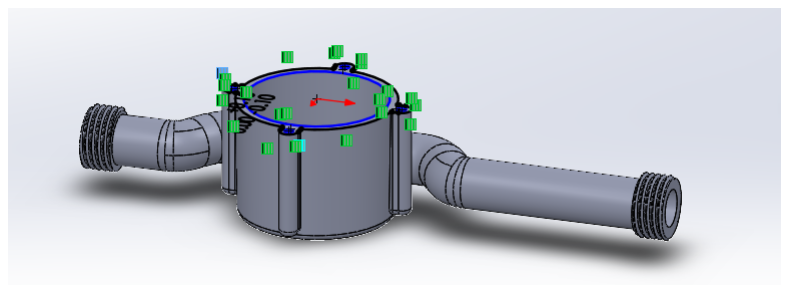
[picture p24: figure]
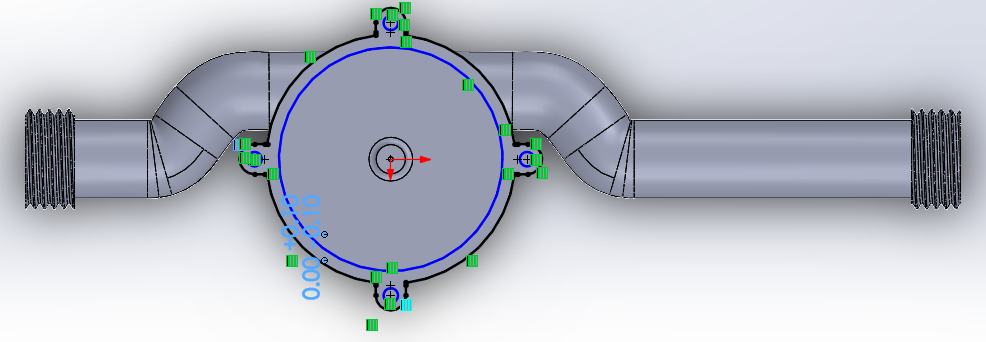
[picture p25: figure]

Figure 19: Top and side views of the internal assembly

## 10 Cost Estimation and Production Scope

This section summarizes the estimated prototype cost of the proposed smart water meter and

outlines the anticipated improvements and cost reductions achievable through large-scale man-

ufacturing.

Table 4: Estimated Prototype Cost (Single Unit)

Component | Cost (LKR)
STM32L0 microcontroller and supporting components SIM800L GSM communication module LiSocl2 Er34615 GSM Load Switch AO3401A MOSFET LDO Regulator XC6206 Boost Converter TPS61023DRLR PCB fabrication, connectors, and miscella-neous components enclosure | 2,800 1,800 7800 50 50 400 5,000 3,000
Total Prototype Cost | 25,900

### 10.1 Production Scaling

Large-scale manufacturing significantly reduces the bill of materials (BOM) through bulk com-

ponent procurement, optimized PCB fabrication, and streamlined assembly processes.

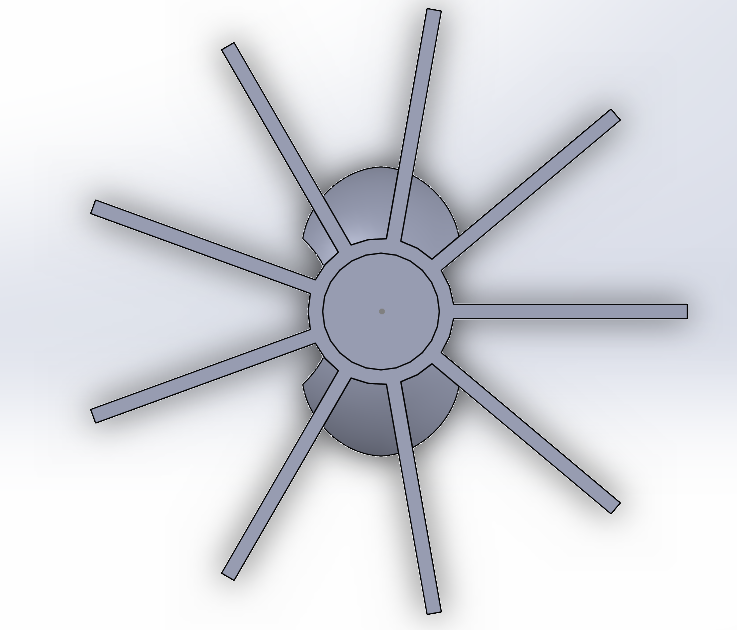
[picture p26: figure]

Figure 20: Top and side views of the turbine rotor

- Following table summarizes the estimated total company cost for a production volume of

1 unit.

Table 5: Estimated Total Company Cost per Unit

Cost Item | Cost (LKR)
Manufacturing cost | 11,300
Packaging and logistics | 700
Cloud hosting and database services (1 year) | 500
Warranty and technical support | 1,000
Administrative and operational expenses | 1,500
Total Company Cost | 15,000
- Bulk purchasing of electronic components to reduce overall BOM cost.
- Custom-designed PCB replacing development modules.
- Industrial-grade IP67 weatherproof enclosure for outdoor deployment.
- Migration from GSM-only communication to LoRaWAN or NB-IoT for improved scala-

bility and lower communication costs.

- Production cloud infrastructure with 99.9% service availability, secure JWT-based au-

thentication, and enterprise-grade data management.

The transition from prototype to commercial deployment will require collaboration with

the NWSDB, including pilot installations, product validation, Memoranda of Understanding

(MoUs), and formal type-approval certification.

## 11 Team Contributions

The successful design and implementation of the Automated IoT Smart Water Meter were made

possible through the collaborative efforts of all team members. The individual responsibilities

and technical contributions of each member are detailed in Table 6.

Table 6: Team Member Contributions

Index No. | Name | Contributions
230680M | W.M.H. Wanigasundara | PCB design (MCU, Sensor), Soldering, PCB Testing, Debugging
230689A | A.H.T.M. Weerakoon | Solidworks Design, Soldering, Integration and Testing, Component selection
230495B | H.W.D. Prabarshana | Solidworks Design, Documentation, Procure-ment
230395T | K.D. Manatunga | Solidworks Design, Soldering, PCB Testing, Integration
230563H | H.D.J.D. Samaranayaka | PCB design (power), Documentation, Web application, Web testing

## 12 Conclusion

The proposed Automated IoT Smart Water Meter offers a practical and cost-effective solution

to Sri Lanka’s Non-Revenue Water (NRW) challenge by replacing conventional manual metering

with an intelligent, IoT-enabled monitoring and billing system. By integrating low-power em-

bedded hardware, GSM communication, cloud-based data management, and user-friendly web

dashboards, the system enables real-time water consumption monitoring, automated billing,

and early leak detection while significantly reducing operational costs and improving billing

accuracy.

The modular hardware architecture, long-life battery-powered operation, and scalable cloud

infrastructure make the system suitable for both residential and utility-scale deployment. Fur-

thermore, the mechanical enclosure has been designed to ensure reliable operation in outdoor

environments while supporting future hardware expansion.

With the PCB design, embedded firmware, cloud backend, and mechanical enclosure al-

ready under development, Team Excalibur is well positioned to deliver a fully functional and

validated prototype by the conclusion of the EN2160 Engineering Design Realization module.

The proposed design also provides a clear pathway toward large-scale manufacturing and de-

ployment, contributing to improved water resource management, reduced Non-Revenue Water

losses, and the digital transformation of Sri Lanka’s water distribution infrastructure.

## References

[1] National Water Supply and Drainage Board (NWSDB), Annual Report 2024. Available:

https://waterboard.lk (Access the latest Annual Reports section.)

[2] Auditor General’s Department of Sri Lanka, Auditor General’s Report on the National

Water Supply and Drainage Board, 2024. Available: https://www.auditorgeneral.gov.

lk (https://www.auditorgeneral.gov.lk)

[3] Japan International Cooperation Agency (JICA), Project for Reduction of Non-Revenue

Water (NRW) in the Greater Kandy Water Supply Area, Final Report, 2015. Available:

https://openjicareport.jica.go.jp

[4] World | Bank, | The | Challenge | of Reducing | Non-Revenue | Water | (NRW) in
Developing | Countries. | Available: | https://ppp.worldbank.org/library/

challenge-reducing-non-revenue-water-nrw-developing-countries-how-private-sector-can-help-look-performance-based-service-contracting (https://ppp.worldbank.org/library/challenge-reducing-non-revenue-water-nrw-developing-countries-how-private-sector-can-help-look-performance-based-service-con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)

[5] United Nations, Sustainable Development Goal 6: Clean Water and Sanitation. Available:

https://sdgs.un.org/goals/goal6

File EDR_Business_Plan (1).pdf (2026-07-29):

# Automated IoT Smart Water Meter

# Business Plan


### TEAM EXCALIBUR

230395T | K.D. Manatunga
230563H | H.D.J.D.Samaranayaka
230680M | W.M.H.Wanigasundara
230689A | A.H.T.M.Weerakoon
230495B | H.W.D.Prabarshana

## EN2160 - Electronic Design Realization

### Department of Electronic and Telecommunication Engineering

### University of Moratuwa

### July 12, 2026

## CONTENTS

1 Problem Statement | 4
2 Stakeholder and Market Analysis | 6
3 Product Technology & Metrology | 8
4 Business Model & Revenue Strategy | 10
5 Cost Estimation & Production Scaling | 12
6 Conclusion | 15

Automated IoT Smart Water Meter | Business Plan

## 1 Problem Statement

The National Water Supply and Drainage Board (NWSDB) faces significant operational and

financial challenges due to the continued reliance on conventional mechanical water metering

systems. High Non-Revenue Water (NRW), inefficient manual processes, limited infrastructure

visibility, and increasing maintenance costs reduce operational efficiency and negatively impact

revenue generation. The key problems addressed by this project are discussed below.

### 1.1 High Non-Revenue Water and Revenue Loss

Non-Revenue Water (NRW) represents treated water that is produced but never billed due

to physical leaks, unauthorized consumption, inaccurate metering, and administrative losses.

According to the NWSDB, Sri Lanka records a national NRW rate between 24.8% and 27%,

while Colombo historically experienced NRW levels approaching 48% before major rehabilita-

tion initiatives.

The financial implications are substantial. NWSDB estimates that every 1% reduction

in NRW generates approximately LKR 790 million in annual savings by reducing treatment,

pumping, maintenance, and administrative costs. Consequently, reducing NRW remains one of

the highest-impact opportunities for improving the financial sustainability of Sri Lanka’s water

sector.

### 1.2 Manual Meter Reading Inaccuracies

The existing billing process relies on manual meter reading performed by field personnel. This

approach is time-consuming and susceptible to transcription errors, delayed billing cycles, es-

timated readings during inaccessible periods, and opportunities for meter tampering.

Furthermore, neither consumers nor utility operators have access to real-time water con-

sumption data, limiting their ability to detect abnormal usage or identify leaks before significant

water losses occur.

### 1.3 Lack of Remote Monitoring and Control

Current mechanical water meters do not provide remote communication or control capabilities.

When pipe bursts, maintenance activities, or customer payment defaults occur, utility personnel

must physically visit each property to inspect the meter or disconnect the water supply.

These manual interventions increase labour requirements, extend response times, and con-

tribute to higher operational costs while delaying corrective actions.

### 1.4 High Maintenance Cost of Conventional Water Meters

Mechanical water meters gradually deteriorate through continuous operation, reducing mea-

surement accuracy and increasing maintenance requirements. A JICA-supported pilot study

conducted in the Harispattuwa Division in 2015 reported an 8.37% defective meter rate, re-

sulting in approximately LKR 7.9 million in repair and maintenance costs within a single

administrative division.

These findings demonstrate that conventional metering infrastructure imposes recurring

maintenance expenses while limiting the ability of utilities to detect faults proactively.

### 1.5 Need for a Smart Water Metering Solution

The limitations of the existing water metering infrastructure highlight the need for a modern,

intelligent metering system capable of providing accurate real-time consumption data, auto-

mated billing support, remote monitoring, leak detection, and improved operational efficiency.

Such a solution has the potential to reduce Non-Revenue Water, lower maintenance costs, and

enhance service delivery for both water utilities and consumers.

## 2 Stakeholder and Market Analysis

The success of the proposed Automated IoT Smart Water Meter depends on addressing the

requirements of multiple stakeholders within Sri Lanka’s water supply ecosystem.

### 2.1 Stakeholders

The project serves three principal stakeholder groups, each with distinct operational require-

ments and expected benefits.

Table 1: Key Project Stakeholders and Their Needs
Stakeholder | Core Needs
NWSDB / Water Util-ities | Real-time monitoring of NRW, automated leak detec-tion, accurate meter readings, reliable billing data, re-duced operation and maintenance costs, and improved network management.
Consumers / House-holds | Transparent water consumption information, accurate and dispute-free billing, mobile access to usage data, leak notifications, and alerts for remote disconnection or maintenance activities.
Government and Reg-ulatory Authorities | Achievement of national NRW reduction targets, au-ditable metering data, improved resource utilization, re-duced subsidy burden, and progress toward Sustainable Development Goal (SDG) 6: Clean Water and Sanita-tion.

### 2.2 Primary Customer

The primary customer for the proposed solution is the NWSDB, together with regional and

provincial water boards responsible for public water distribution.

Unlike consumer-oriented products, the proposed business follows a Business-to-Government

(B2G) and Business-to-Business (B2B) model, targeting a limited number of large institutional

customers. This approach enables the company to focus its commercialization strategy on

utility procurement processes, pilot deployments, regulatory approvals, and long-term service

agreements rather than mass-market retail sales.

### 2.3 Market Validation

To validate market demand and refine product requirements, we conducted a stakeholder survey

involving prospective users and utility representatives. The survey evaluated awareness of smart water metering technologies, willingness to adopt the proposed solution, and key concerns

related to implementation.

The findings indicated strong interest in smart metering, particularly for features such as

real-time consumption monitoring, automated billing, leak detection, and mobile access to

usage information. Respondents also identified installation cost, data privacy, and long-term

reliability as important considerations for adoption.

## 3 Product Technology & Metrology

The Automated IoT Smart Water Meter developed combines low-power embedded hardware

with wireless communication and cloud-based analytics to provide accurate, real-time water

consumption monitoring. The system is designed for long-term deployment in residential wa-

ter distribution networks while maintaining low manufacturing costs, minimal maintenance

requirements, and extended battery life.

### 3.1 Hardware Stack Overview

The hardware architecture has been designed specifically for low-power, high-reliability opera-

tion in outdoor utility environments. Instead of employing costly ultrasonic flow sensors, the

proposed design utilizes an efficient turbine-based flow measurement mechanism, significantly

reducing manufacturing cost while maintaining the accuracy required for residential water me-

tering.

The complete system consists of five major layers:

- Flow Metering Unit: A turbine rotor housed within a hydrodynamically optimized

flow chamber.

- Embedded Controller: An STM32L0 ultra-low-power microcontroller responsible for

pulse counting, flow computation, power management, and communication control.

- Wireless Communication: A SIM800L GSM/GPRS module that periodically trans-

mits metering data to the cloud through existing cellular networks.

- Cloud Backend: A Supabase cloud database used for secure storage, synchronization,

and analytics of meter data.

- Software Platform: WaterboardOS, a Software-as-a-Service (SaaS) dashboard that en-

ables utilities to monitor consumption, detect anomalies, and manage customers remotely.

### 3.2 Flow Sensing and Computational Logic

Water entering the meter passes through a standardized cylindrical chamber containing an

eight-blade turbine rotor. As the flow rate increases, the turbine rotates proportionally to the

volume of water passing through the chamber.

Permanent magnets embedded within the turbine blades pass a waterproof Hall-effect sen-

sor during rotation, generating a sequence of electrical pulses. The STM32L0 microcontroller

counts these pulses and converts them into instantaneous flow rate and cumulative water con-

sumption using calibration constants stored in memory.

The processed data are periodically transmitted via the GSM communication module to

the cloud backend, where they are visualized through the WaterboardOS dashboard and the

AquaSync consumer application. This architecture enables continuous remote monitoring, au-

tomated billing support, and early leak detection.

## 4 Business Model & Revenue Strategy

We adopts a Business-to-Government (B2G) and Business-to-Business (B2B) business model,

targeting public water utilities as the primary customers. The business generates revenue

through hardware sales, subscription-based software services, and future performance-based

partnerships. This diversified revenue strategy ensures both immediate income from meter

deployment and recurring revenue from cloud-based services.

### 4.1 Primary Business Model: B2G Hardware and Platform

The primary source of revenue is the sale of IoT smart water meters to the NWSDB and, in

the future, regional and provincial water authorities. Each hardware deployment is bundled

with access to the WaterboardOS cloud platform and the AquaSync consumer application.

A phased commercialization strategy is proposed:

- Pilot Deployment

A limited deployment of approximately 100–1,000 smart meters will be supplied to NWSDB

at or near production cost. The objective of this phase is to validate field performance,

collect operational data, and support product certification, regulatory approval, and long-

term partnership agreements.

- Large-Scale Deployment

Following successful pilot validation, the system will be deployed on a larger scale. The

expected selling price is approximately LKR 18,500–25,000 per meter, depending on

production volume and hardware configuration. Future product versions may incorpo-

rate enhanced enclosure protection (IP67) and communication technologies such as Lo-

RaWAN or NB-IoT for wider network coverage. Installation activities can be performed

by NWSDB’s existing field teams, minimizing additional operational costs.

- Platform Subscription

In addition to hardware sales, recurring revenue will be generated through subscription

fees for the WaterboardOS platform. These subscriptions cover secure cloud hosting,

data storage, software maintenance, analytics, technical support, and continuous platform

updates. The software platform is designed to provide high availability with a target

uptime of 99.9%, while ensuring secure access through JWT-based authentication and

role-based data management.

### 4.2 Performance-Based Contracting

An alternative commercialization strategy involves performance-based contracting. Since NWSDB

estimates that each one-percentage-point reduction in NRW saves approximately LKR 790

million annually, a gain-sharing model could be introduced in which our team receives a

negotiated percentage of the verified financial savings generated through smart meter deploy-

ment.

This approach reduces the utility’s upfront capital investment while aligning the incentives of

both parties toward measurable reductions in water losses and improved operational efficiency.

### 4.3 Secondary Market Opportunities

Following successful validation with NWSDB, the proposed technology can be expanded into

additional market segments.

Potential secondary customers include:

- Private condominium and apartment management companies requiring internal water

sub-metering.

- Industrial and commercial facilities seeking automated water consumption monitoring.
- Hotels, hospitals, universities, and large institutional campuses.
- Regional water utilities in neighbouring countries experiencing similar NRW challenges.

The modular hardware architecture and cloud-based software platform enable the solution

to be adapted for a wide range of utility-scale and commercial water management applications,

supporting future regional expansion and long-term business growth.

## 5 Cost Estimation & Production Scaling

This section presents the estimated manufacturing cost of the prototype, the projected cost

reductions achievable through large-scale production, and an illustrative business case demon-

strating the economic viability of the proposed smart water metering solution.

### 5.1 Prototype Cost Estimation

The current prototype has been developed using commercially available development compo-

nents suitable for testing and validation. As a result, the prototype cost is higher than the

expected production cost.

Table 2: Estimated Prototype Cost (Single Unit)
Component | Cost (LKR)
STM32L0 microcontroller and supporting components SIM800L GSM communication module LiSocl2 Er34615 GSM Load Switch AO3401A MOSFET LDO Regulator XC6206 Boost Converter TPS61023DRLR PCB fabrication, connectors, and miscella-neous components enclosure | 2,800 1,800 7800 50 50 400 5,000 3,000
Total Prototype Cost | 25,900

### 5.2 Production Scaling

Large-scale manufacturing significantly reduces the bill of materials (BOM) through bulk com-

ponent procurement, optimized PCB fabrication, and streamlined assembly processes.

The projected production cost for a manufacturing volume of approximately 10,000 units

is:

- Target manufacturing cost: LKR 11,300 per unit
- Bulk purchasing of electronic components to reduce overall BOM cost.
- Custom-designed PCB replacing development modules.
- Industrial-grade IP67 weatherproof enclosure for outdoor deployment.
- Migration from GSM-only communication to LoRaWAN or NB-IoT for improved scala-

bility and lower communication costs.

- Production cloud infrastructure with 99.9% service availability, secure JWT-based au-

thentication, and enterprise-grade data management.

The transition from prototype to commercial deployment will require collaboration with

the NWSDB, including pilot installations, product validation, Memoranda of Understanding

(MoUs), and formal type-approval certification.

### 5.3 Illustrative Business Case

The financial viability of the proposed solution is supported by the significant economic impact

of reducing NRW.

Assuming a deployment of approximately 10,000 smart water meters, the estimated hard-

ware investment would be:

10, 000 × LKR 11, 300 = LKR 113, 000, 000

According to NWSDB estimates, every 1% reduction in national Non-Revenue Water

generates approximately LKR 790 million in annual savings through reduced treatment,

pumping, maintenance, and administrative costs.

Therefore, even if a deployment of 10,000 smart meters contributes to only a fraction of a

one-percentage-point reduction in NRW, the resulting financial savings have the potential to

exceed the initial hardware investment within a relatively short period.

The selling price of the product was determined by considering the total production cost,

desired profit margin, and market competitiveness. The proposed selling price is calculated

using the following equation:

Selling Price = Total Cost + Desired Profit

The profit margin is calculated as:

Profit Margin (%) = 18,080 − 11,300 18,080

× 100

For the proposed product, the total manufacturing cost is estimated as Rs. 11, 300, and the

selected selling price is Rs. 25, 000. Therefore, the profit margin is:

Profit Margin (%) = 25, 000 − 11, 300 25, 000

× 100

= 54.8%

Hence, the product can be sold at a price of Rs. 25, 000, providing a profit margin of 54.8%

while maintaining affordability and market competitiveness.

Although the exact return on investment will depend on deployment scale, installation costs,

and network characteristics, this analysis demonstrates a strong economic justification for pilot

deployment followed by large-scale implementation.

## 6 Conclusion

Our Automated IoT Smart Water Meter transforms a well-documented and financially signif-

icant national challenge, namely Non-Revenue Water (NRW) in Sri Lanka, into a practical

engineering and commercial opportunity.

The proposed solution combines low-power hardware, reliable flow measurement, wireless

communication, and cloud-based analytics to address the limitations of conventional mechanical

water metering systems. With a functional prototype, a clearly defined bill of materials, and

an established cost-reduction pathway for large-scale manufacturing, the project demonstrates

strong potential for real-world deployment.

Furthermore, the development of the two-sided software ecosystem, consisting of Water-

boardOS for utility management and AquaSync for consumer engagement, provides a com-

plete smart water management platform rather than a standalone metering device. This inte-

grated approach enables real-time monitoring, improved billing accuracy, leak detection, and

enhanced operational decision-making.

The significant financial impact associated with reducing NRW strengthens the commercial

feasibility of the proposed solution. NWSDB’s own estimation of approximately LKR 790

million in annual savings for every 1% reduction in NRW provides a strong foundation

for the business case and highlights the value of deploying intelligent metering infrastructure.

With further field validation, regulatory approval, and collaboration with NWSDB, our

solution has the potential to progress from an academic prototype into a scalable utility tech-

nology capable of improving water management, reducing national water losses, and supporting

sustainable infrastructure development in Sri Lanka.

## References

[1] National Water Supply and Drainage Board (NWSDB), Annual Performance Report 2024.

Battaramulla, Sri Lanka: NWSDB, 2024. [Online]. Available: https://www.waterboard.

lk (https://www.waterboard.lk)

[2] Auditor General’s Department of Sri Lanka, Report of the Auditor General on the Na-

tional Water Supply and Drainage Board. Colombo, Sri Lanka: Auditor General’s De-

partment, 2024. [Online]. Available: https://www.auditorgeneral.gov.lk/web/images/

audit-reports/upload/state_corporation/ (https://www.auditorgeneral.gov.lk/web/images/audit-reports/upload/state_corporation/)

[3] Japan International Cooperation Agency (JICA) and National Water Supply and Drainage

Board, Hand Book for Water Consumers, 1st ed., Greater Kandy Water Supply Project

(GKWSP). Kandy, Sri Lanka: JICA/NWSDB, Nov. 2014, ISBN 978-955-4731-01-1.

[4] Asian Development Bank, Institutional Development of the National Water Supply and

Drainage Board, TA 48276-001. Manila, Philippines: ADB. [Online]. Available: https:

//www.adb.org/projects/48276-001/main

[5] Asian Development Bank, “From Water Loss to Savings: A Nonrevenue Water Interven-

tion in Sri Lanka,” Development Asia. [Online]. Available: https://development.asia/

case-study/water-loss-savings-nonrevenue-water-intervention-sri-lanka (https://development.asia/case-study/water-loss-savings-nonrevenue-water-intervention-sri-lanka)

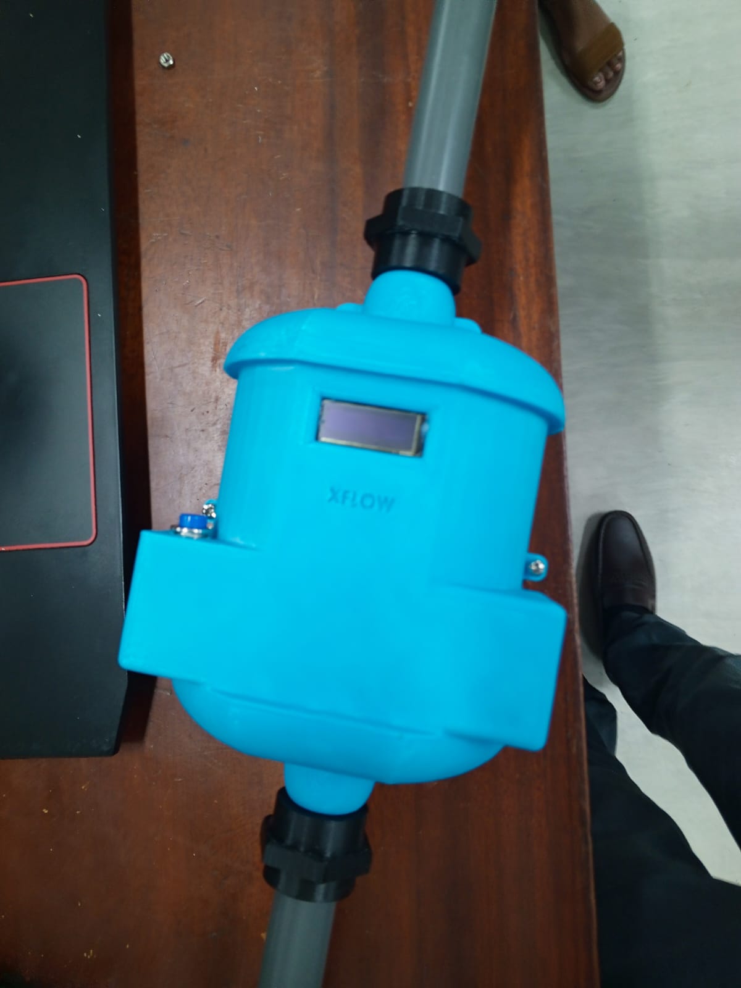
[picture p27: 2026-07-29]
Final product images/WhatsApp Image 2026-07-29 at 1.20.56 PM.jpeg

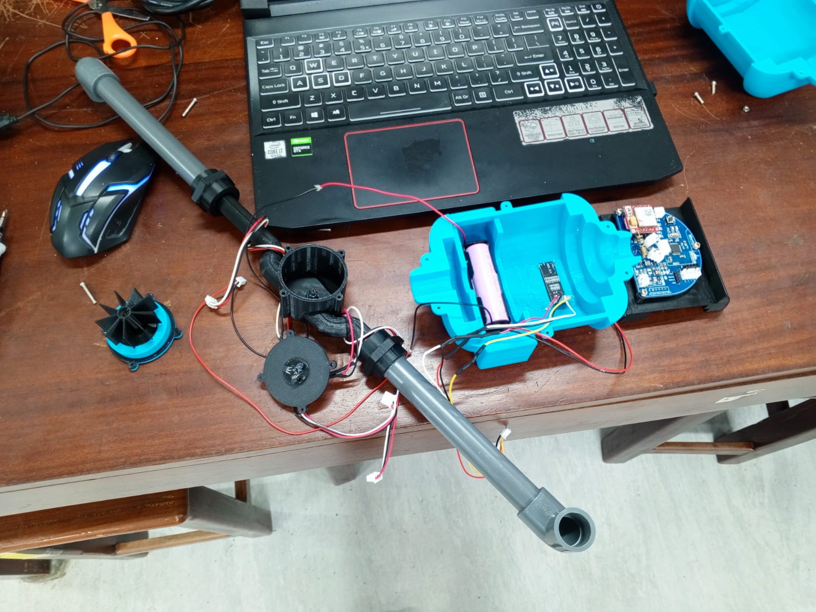
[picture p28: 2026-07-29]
Final product images/ttt.jpeg

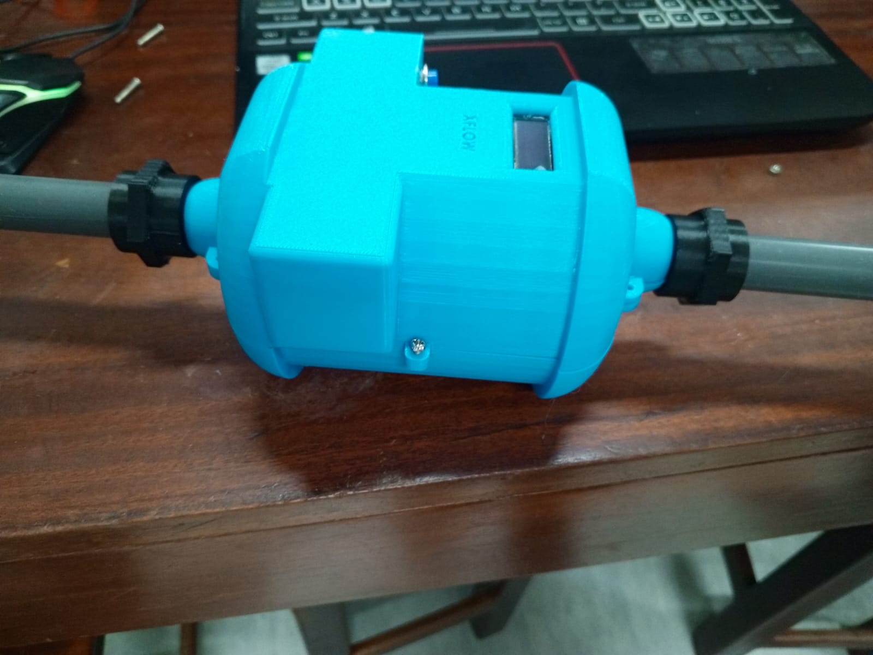
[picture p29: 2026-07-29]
Final product images/WhatsApp Image 2026-07-29 at 1.20.57 PM.jpeg

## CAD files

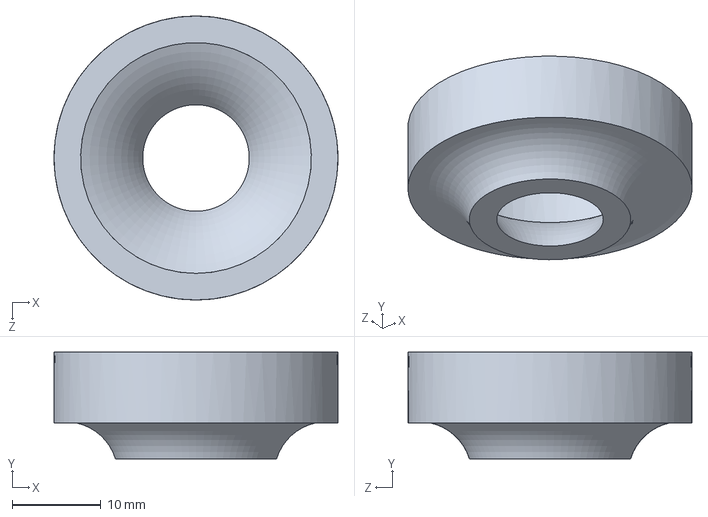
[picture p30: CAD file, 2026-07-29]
water_meter_solidworks/fan_bracket_tm_v1.SLDPRT
32.0 x 12.0 x 32.0 mm

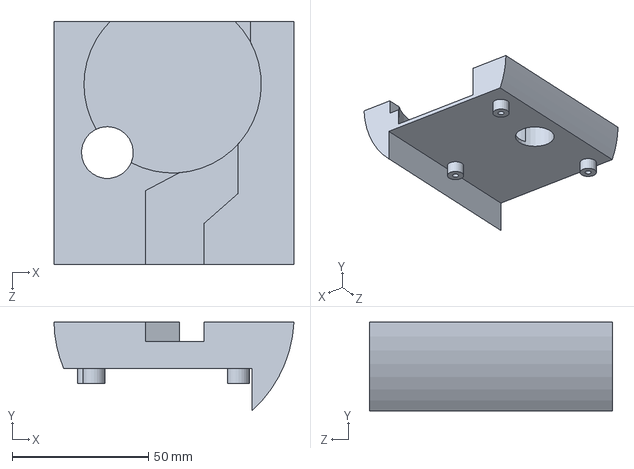
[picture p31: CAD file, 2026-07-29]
water_meter_solidworks/shell_01.SLDPRT
88.0 x 32.5 x 89.0 mm

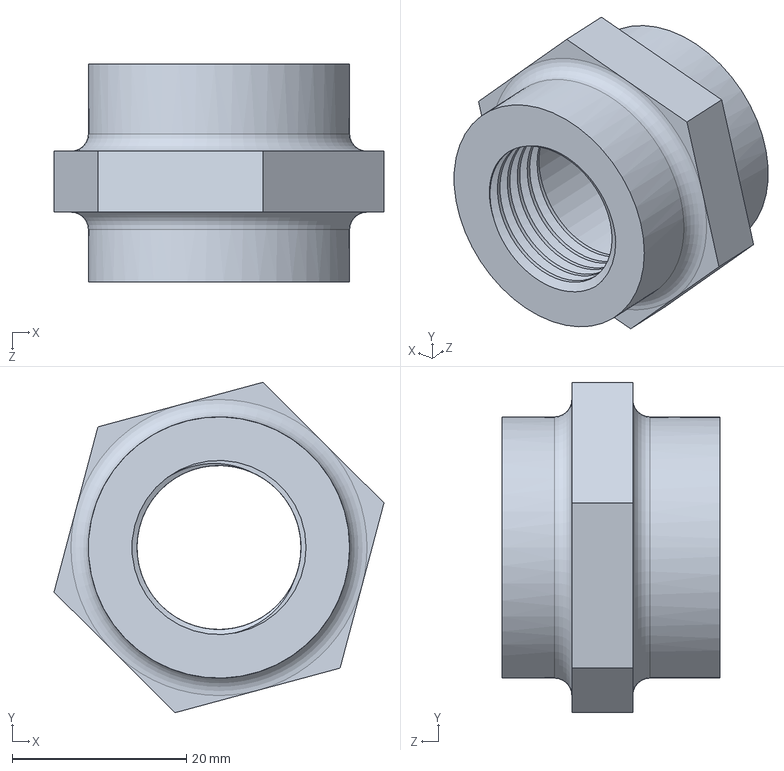
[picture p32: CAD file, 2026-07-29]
water_meter_solidworks/socket_test.SLDPRT
37.9 x 37.9 x 25.0 mm

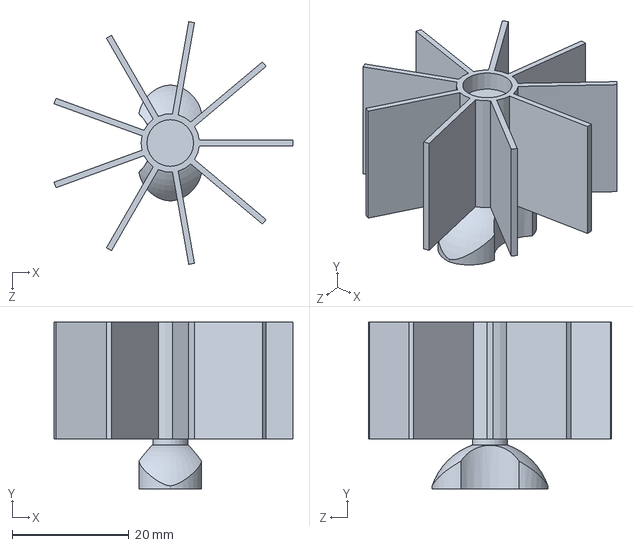
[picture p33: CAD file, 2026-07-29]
water_meter_solidworks/FanD2_tm_v1.SLDPRT
40.9 x 28.5 x 41.5 mm

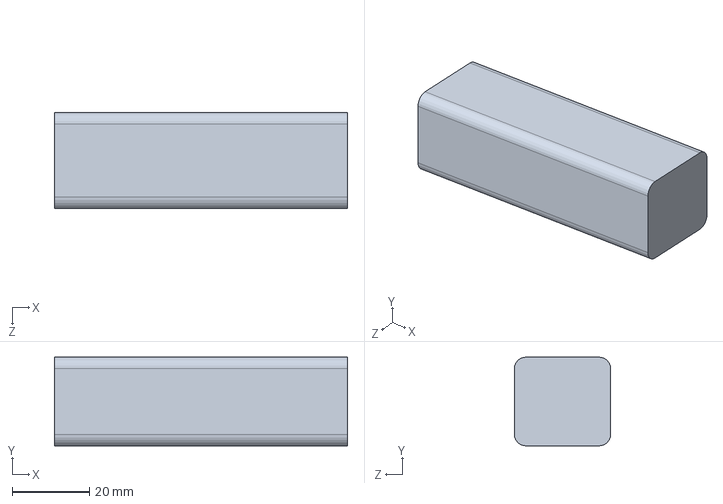
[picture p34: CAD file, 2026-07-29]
water_meter_solidworks/Battery.SLDPRT
76.0 x 23.0 x 25.0 mm

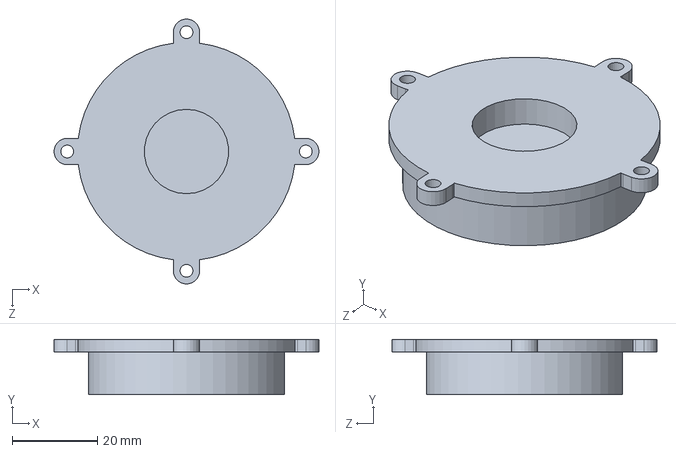
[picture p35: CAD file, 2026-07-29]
water_meter_solidworks/lid_tm_v1(1).SLDPRT
62.2 x 13.0 x 62.2 mm

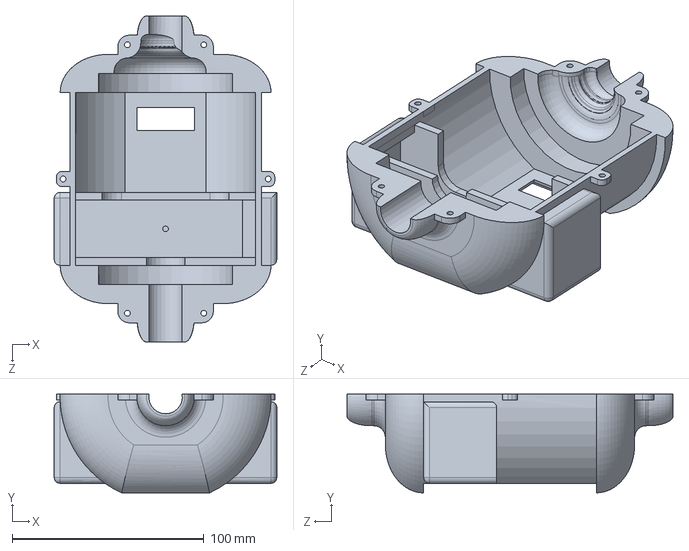
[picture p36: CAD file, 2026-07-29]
water_meter_solidworks/watermeter_cover_part_2_version_02.SLDPRT
116.1 x 51.5 x 170.0 mm

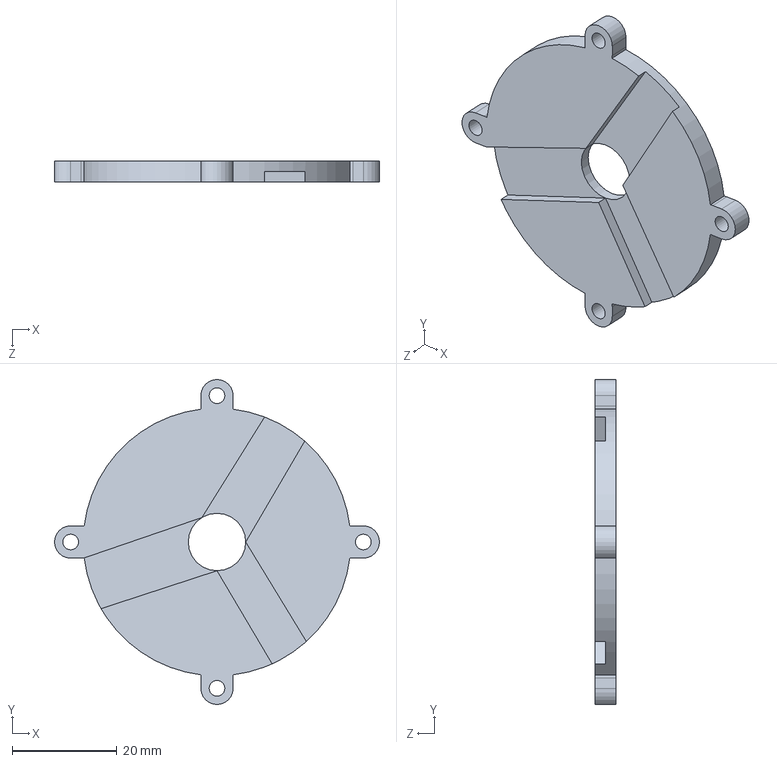
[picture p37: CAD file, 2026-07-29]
water_meter_solidworks/top_lid.SLDPRT
62.2 x 62.2 x 4.00 mm

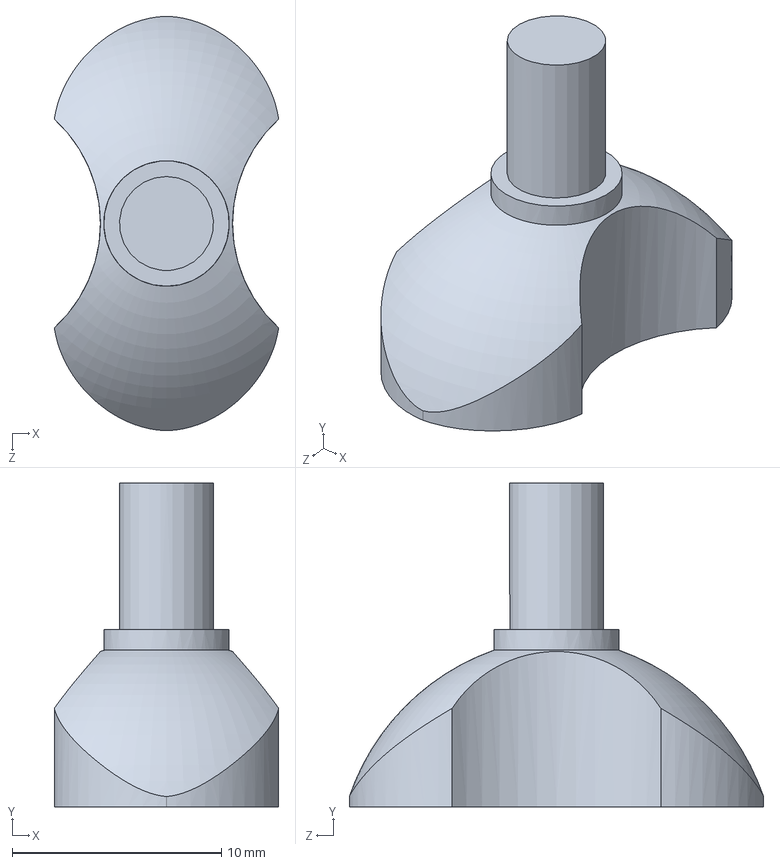
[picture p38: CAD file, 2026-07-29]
water_meter_solidworks/Fan_test_1.SLDPRT
10.7 x 15.5 x 19.8 mm

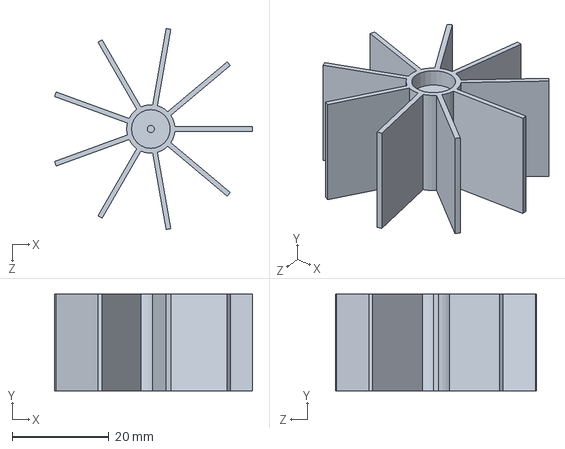
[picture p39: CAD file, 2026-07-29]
water_meter_solidworks/Fan_test_2.SLDPRT
40.9 x 20.0 x 41.5 mm

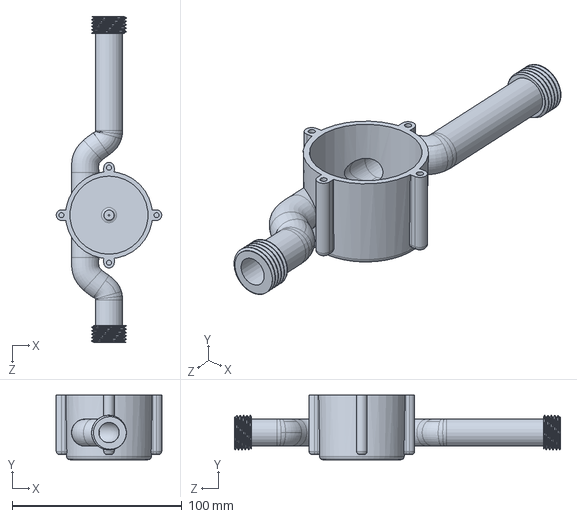
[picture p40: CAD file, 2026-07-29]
water_meter_solidworks/PF_v02.SLDPRT
62.2 x 38.0 x 192.0 mm

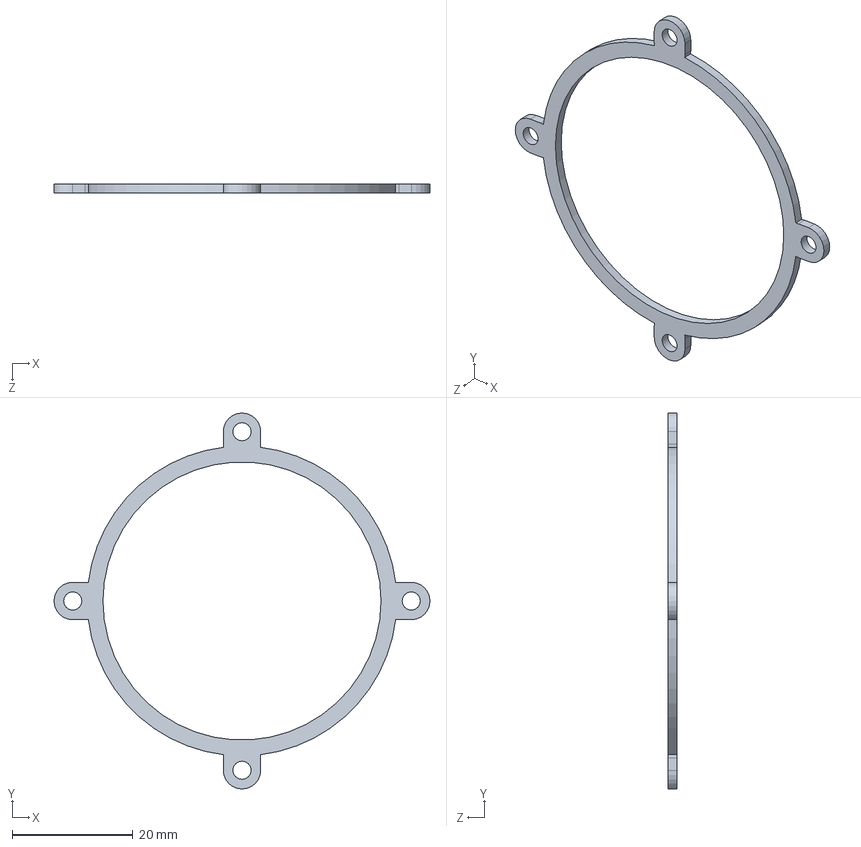
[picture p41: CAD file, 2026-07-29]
water_meter_solidworks/tank_wosher_v_1.SLDPRT
62.2 x 62.2 x 1.50 mm

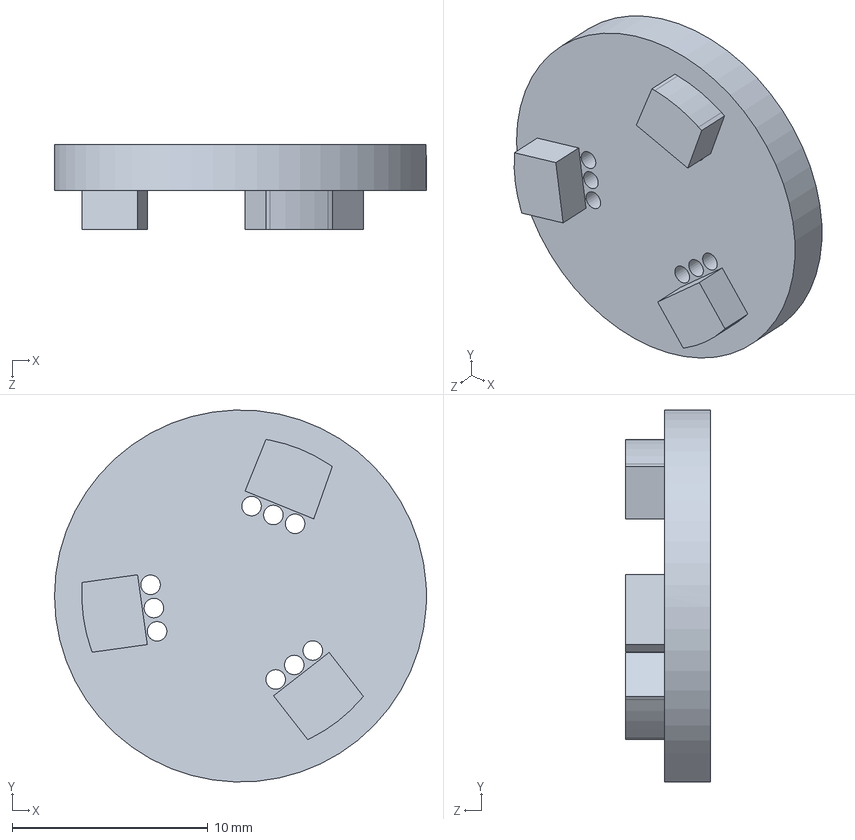
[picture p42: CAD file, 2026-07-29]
water_meter_solidworks/sensor_wosher.SLDPRT
19.0 x 19.0 x 4.35 mm

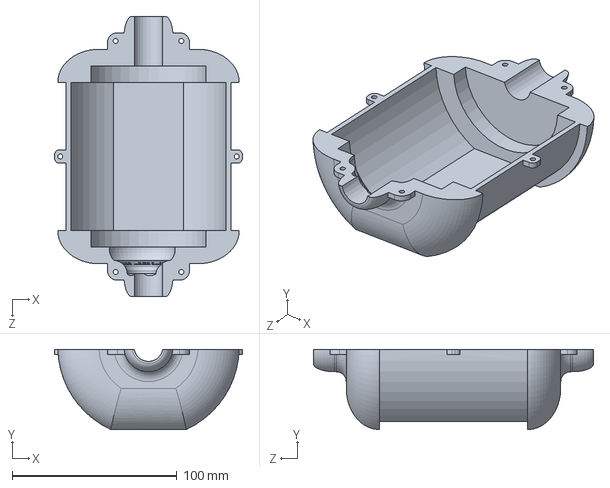
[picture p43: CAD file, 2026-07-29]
water_meter_solidworks/watermeter_cover_half_version_02_final.SLDPRT
114.0 x 48.5 x 170.0 mm

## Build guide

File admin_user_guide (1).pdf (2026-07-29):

# Waterboard Management System

## System Administrator Guide

Version: 1.0

## Prepared for:

Department of Electronic and Telecommunication Engineering University of Moratuwa

Waterboard Management System | Administrator Guide

## Revision History

Version | Date | Description of Change | Author
1.0 | July 11, 2026 | Initial release of the Administrator Guide. | Admin Team

## Contents

Revision History | 1
1 1. Introduction | 3
2 2. System Overview | 3
3 3. Login | 3
4 4. Dashboard | 4
5 5. Client Management | 5
6 6. Device Management | 5
7 7. Tariff Management & Billing | 6
8 8. Bulk Notifications | 7
9 9. System Settings | 7
10 10. Troubleshooting | 8
11 11. Frequently Asked Questions | 8
12 12. Contact & Support | 9

## 1 1. Introduction

Purpose

This document provides system administrators with the necessary instructions to manage, monitor, and configure the Waterboard Management System.

Audience

This guide is intended for IT administrators, network operators, and billing managers responsible for the daily operation of the smart water meter network.

Scope

This manual covers software platform navigation, user management, device monitoring, billing configuration, and basic system troubleshooting. Detailed electronic schematics and physical maintenance procedures are covered in the separate Hardware Maintenance Manual.

Prerequisites

- A modern web browser (Google Chrome, Mozilla Firefox, or Microsoft Edge).
- Authorized administrative credentials and the current system authorization code.
- A stable internet connection.

## 2 2. System Overview

The Waterboard Management System is a centralized platform that aggregates telemetry data from field-deployed smart meters.
Each deployed water meter contains:
- A core processing microcontroller.
- A flow sensing unit (magnetic rotation detection).
- A GSM communication module for remote data transmission.
- A long-life, industrial-grade battery.

The admin portal continuously processes this hardware data into actionable billing and operational metrics.

## 3 3. Login

Purpose: Authenticate and securely access the administrator portal.

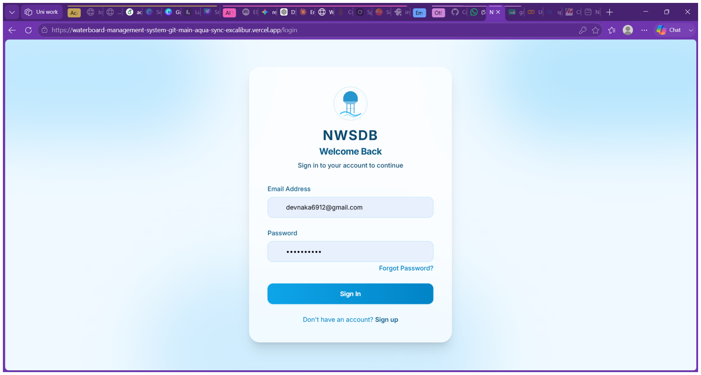
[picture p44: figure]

Admin Login Interface

Procedure:

1. Navigate to the admin portal URL in your web browser.
2. Enter your authorized administrator Email.
3. Enter your Password.
4. Enter the mandatory authorization code: WATER2026.
5. Click Login.

Expected Result: The system authenticates the credentials and redirects to the Admin Dashboard.
Notes:
- Failed attempts exceeding 5 tries will temporarily lock the account for 15 minutes.

## 4 4. Dashboard

Purpose: Provide a high-level overview of system health and key metrics.

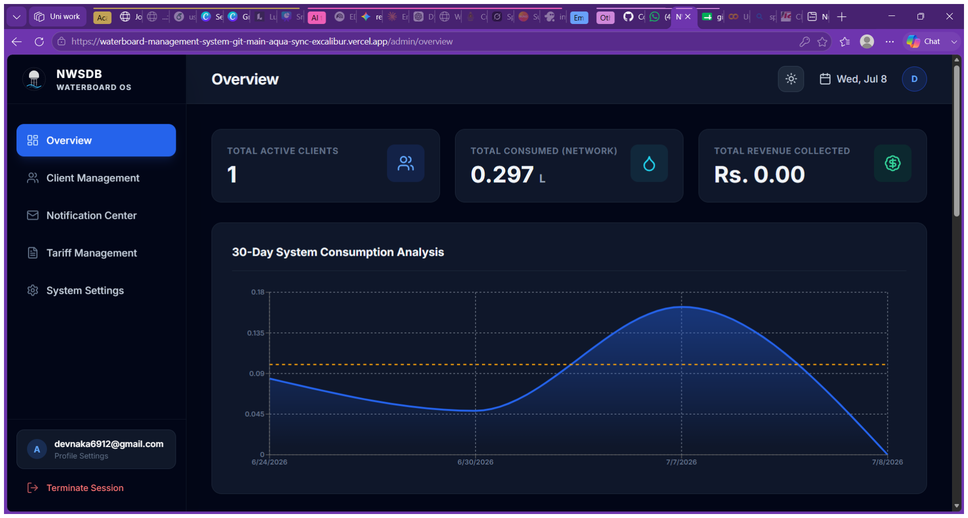
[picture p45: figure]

Dashboard Overview

Procedure:

1. Log in to the system. The Dashboard is the default landing page.
2. Review the Global Metrics panel for total active clients and revenue.
3. Review the System Status panel for offline hardware warnings.

## 5 5. Client Management

Purpose: Manage customer accounts, update profiles, and review individual consumption. Procedure:

1. Navigate to Client Management using the left sidebar.
2. Search for the client using the top search bar (by name or meter ID).
3. Click View Details next to the desired client.
4. Edit the required fields (e.g., contact information, account status).
5. Click Save.

Expected Result: The client profile is updated successfully and reflects immediately in the database.
Notes:
- Email addresses must be unique across the system.
- Deleted accounts cannot be recovered. Use ”Suspend” instead of deleting where possible.

## 6 6. Device Management

Purpose: Monitor the operational status and data synchronization of field-deployed water meter assets.

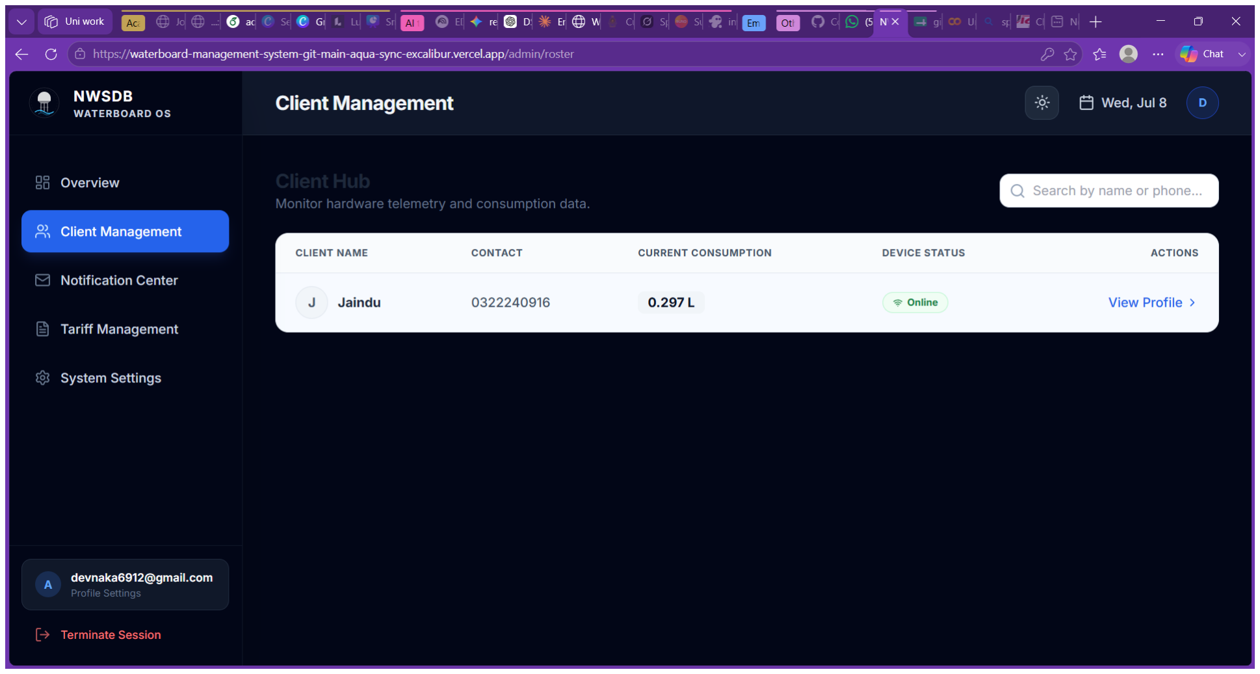
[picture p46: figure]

Device Management Interface

Procedure:

1. Navigate to Devices in the primary dashboard sidebar.
2. Select the desired meter ID from the fleet register table.
3. Validate the following interface metrics:
- Total Consumption: The cumulative water usage recorded by the hardware.
- Last Handshake Timestamp: Indicates the exact date and time the system last received a telemetry payload from the GSM module.

Notes:

- Telemetry data updates on an hourly cycle. If the Last Handshake Timestamp exceeds 24 hours, the system marks the node state as ”Offline,” indicating a transmission failure.

## 7 7. Tariff Management & Billing

Purpose: Configure pricing structures and unit rates for water consumption. Procedure:

1. Navigate to Tariffs & Billing.
2. Select the billing region or tier you wish to modify.
3. Update the Unit Rate (per Liter) or Fixed Charge fields.
4. Click Apply to Network.

Expected Result: The new pricing structure will be applied to the next billing cycle. Current open invoices will not be affected.

## 8 8. Bulk Notifications

Purpose: Broadcast alerts, maintenance updates, or policy changes to clients. Procedure:

1. Navigate to Notifications.
2. Click Create New Message.
3. Select the target audience (All Clients or Specific Region).
4. Type the message subject and body.
5. Click Send Notification.

## 9 9. System Settings

Purpose: Manage global application parameters and administrator profiles. Procedure:

1. Navigate to Settings.
2. Update application preferences or click Admin Profile to change your password.
3. Click Save Changes.

## 10 10. Troubleshooting

Diagnostic Procedures & Core Issues

Procedure: Offline Device Diagnostics

Because the smart meters transmit minimal payload data to conserve power, remote telemetry for battery and signal strength is not available on the dashboard. Diagnostics require isolating the fault using timestamp data followed by a localized field inspection. Core Issue: Device Status shows as ’Offline’ (No data received for ¿ 24 hours).
Step 1: Verify the Data Interruption Time
1. Navigate to Device Management and check the Last Handshake Timestamp.
2. If multiple devices in the same geographic region went offline at the exact same timestamp, the issue is likely a regional cellular network outage rather than a hardware failure.
3. If only a single device is offline, flag the unit for a physical field inspection.
Step 2: Field Inspection - Power Status
1. Dispatch a technician to the physical meter location.
2. Press the local wake button on the front face of the meter.
3. Result A: If the digital display remains blank, the internal power cell has been exhausted. The unit requires a battery replacement.
4. Result B: If the display wakes up and shows the Liters consumed, the hardware is powered and the issue is related to the GSM transmission.
Step 3: Field Inspection - GSM Signal Shielding
1. If the meter has power but is not transmitting, inspect the installation environment.
2. Ensure the client has not placed heavy metal enclosures, dense objects, or RFshielding materials around the meter that would block the GSM module from reaching the cellular tower.

Expected Result: The administrator successfully categorizes the failure as a network outage, a dead battery, or RF shielding, allowing for accurate maintenance dispatch.

## 11 11. Frequently Asked Questions

Q: Can I recover a deleted client profile?
A: No, deleted profiles are permanently removed from the active database for privacy compliance. Always use the ’Suspend’ feature unless a permanent deletion is explicitly required.

Q: How often do the meters transmit data?
A: Under standard configuration, meters transmit telemetry data hourly to optimize battery life while providing near real-time billing data.

## 12 12. Contact & Support

For advanced technical assistance, database architecture inquiries, or hardware replacements, please contact the development team:

- Department: Electronic and Telecommunication Engineering (ENTC)
- Institution: University of Moratuwa
- System Documentation: Refer to the Internal Backbone Network Guide for routing and server configurations.

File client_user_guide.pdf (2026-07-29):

# Waterboard Management System

## Client Quick Start & User Guide

Version: 1.0

## Prepared for:

Department of Electronic and Telecommunication Engineering University of Moratuwa

Waterboard Management System | Client User Guide

## Revision History

Version | Date | Description of Change | Author
1.0 | July 11, 2026 | Initial release of the Client User Guide. | Admin Team

## Contents

Revision History | 1
1 1. Introduction | 3
2 2. Your Smart Meter Hardware | 3
3 3. Account Access | 3
4 4. Client Dashboard | 4
5 5. Billing & Payments | 4
6 6. Account Profile | 5
7 7. Troubleshooting & FAQ | 5

## 1 1. Introduction

Purpose

This guide provides clients with the necessary instructions to monitor their water consumption, manage their billing, and interact with the physical smart water meter installed at their property.

Audience

This manual is intended for residential and commercial end-users connected to the Waterboard Management System.

Prerequisites

- A modern web browser (Google Chrome, Mozilla Firefox, or Safari) or a mobile smartphone.
- A registered email address to create and manage your account.

## 2 2. Your Smart Meter Hardware

Your property is equipped with a state-of-the-art smart meter that automatically tracks your usage and syncs with your online portal, eliminating the need for manual readings.
The physical meter is designed to be highly autonomous and features:
- A high-precision internal flow sensing unit.
- An integrated wireless cellular module to transmit usage data to the administration.
- A long-lasting internal battery designed to operate for years without replacement.

Reading the Local Display: To conserve battery life, the digital screen on your meter remains off during standard operation. If you wish to check your exact current reading locally:

1. Locate the wake button on the front face of the meter.
2. Press the button firmly once.
3. The display will illuminate briefly, showing your total water consumed in Liters.

Important Installation Note: Ensure the space around the meter remains clear. Do not place heavy metal enclosures, boxes, or dense objects around the meter, as this can block the wireless signal and prevent your dashboard from updating.

## 3 3. Account Access

Purpose: Register for a new account or log in to view your usage. Procedure (New Users):

1. Navigate to the Client Portal URL.
2. Click Register or Sign Up.
3. Fill in your personal details (Name, Email, Password) and your assigned Meter ID.
4. Click Submit to create your account.

Procedure (Returning Users):

1. Navigate to the Client Portal URL.
2. Enter your registered Email and Password.
3. Click Login to access your Dashboard.

Notes: If you forget your password, use the Forgot Password link to receive a secure reset email.

## 4 4. Client Dashboard

Purpose: Provide a quick, visual overview of your recent water consumption.

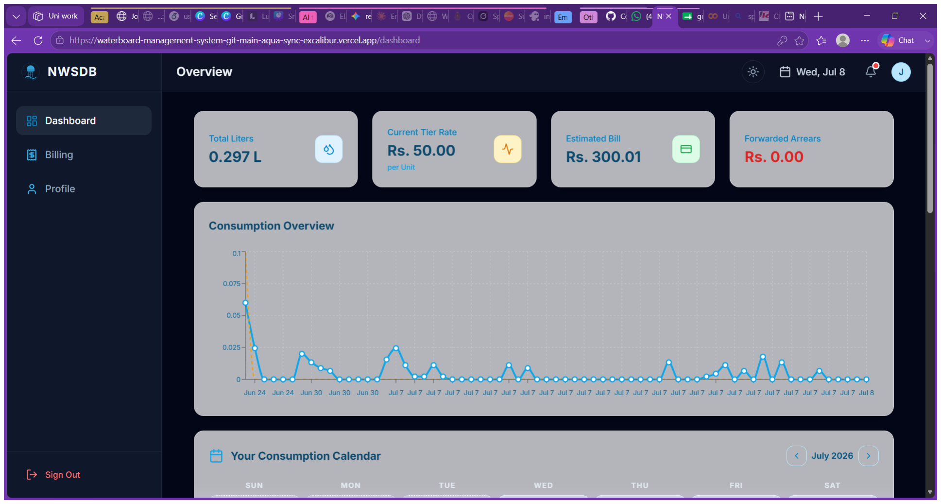
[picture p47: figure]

Client Dashboard Interface

Procedure:

1. Log in to your account. The Dashboard is your default view.
2. Review the Usage Trends charts to see visual graphs of your recent water consumption.
3. Check the summary widget for your current billing cycle estimates.

## 5 5. Billing & Payments

Purpose: Review your generated invoices and track payment statuses. Procedure:

1. Navigate to the Billing section using the portal menu.
2. Select a specific invoice to view its detailed breakdown (Total usage, assigned tariffs, taxes, and final amount).
3. Verify the payment status (e.g., Paid, Pending, or Overdue).

## 6 6. Account Profile

Purpose: Keep your contact details and security credentials up to date. Procedure:

1. Navigate to Profile or Settings.
2. Edit your contact number or email address as needed.
3. To change your password, enter your current password followed by the new desired password.
4. Click Save Changes.

## 7 7. Troubleshooting & FAQ

Common Issues

Issue: My dashboard hasn’t updated my usage today.

- Explanation: To conserve the internal battery, your smart meter transmits data to the portal periodically (typically every hour).
- Action: Wait for the next hourly synchronization cycle. If it has been more than 24 hours, check that no large metal objects are blocking the meter’s wireless signal.

Issue: The physical meter display is completely blank.

- Explanation: The screen turns off automatically to save power.
- Action: Press the physical ”Wake” button on the front of the meter. If the screen still does not turn on after pressing the button, please contact support for a battery inspection.

Q: Can I pay my bill directly through the portal?
A: Please refer to the specific payment instructions listed on your generated invoice in the Billing tab for accepted payment methods.

Q: How do I know if I have a water leak?
A: Monitor your Usage Trends graph on the Dashboard. If you notice a steady, continuous increase in consumption during hours when no water is being used (like overnight), you may have a plumbing leak.

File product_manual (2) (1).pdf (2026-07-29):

[ Insert Company/Project Logo Here ]

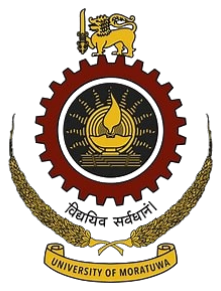
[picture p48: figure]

# Smart Water Meter

## Product Manual

Product Version: 1.0
Document Version: 1.0

## Prepared by:

Team Excalibur
Department of Electronic and Telecommunication Engineering University of Moratuwa

Waterboard Smart Water Meter | Product Manual

## Revision History

Version | Date | Description of Change | Author
1.0 | July 11, 2026 | Initial Release of Product Manual | Development Team

## Contents

Revision History | 1
1 Introduction | 3
2 Product Overview | 3
3 Safety Information | 4
4 Package Contents | 4
5 Product Components | 4
6 Internal Hardware Overview | 4
7 Technical Specifications | 5
8 Installation | 6
9 Device Operation | 6
10 LED Indicators | 6
11 Maintenance | 6
12 Troubleshooting | 7
13 Frequently Asked Questions | 7
14 Warranty | 7
15 Regulatory & Safety Information | 7
16 Appendix | 8

## 1 Introduction

### 1.1 Purpose

The Waterboard Smart Water Meter is designed to automatically monitor, record, and securely transmit water consumption data. It eliminates the need for manual meter reading by providing near real-time telemetry to the centralized Waterboard Management System.

### 1.2 Scope

This manual covers the installation, operation, safety guidelines, and basic maintenance of the Smart Water Meter. It provides an overview of the internal hardware for service technicians but does not replace the comprehensive Hardware Maintenance Manual required for board-level repairs.

### 1.3 Intended Users

- Customers: For basic operation and understanding of the local display.
- Water Board Technicians: For field installation and troubleshooting.
- Maintenance Personnel: For diagnostic reviews and battery replacement.

## 2 Product Overview

The Smart Water Meter is an ultra-low-power IoT edge device engineered for extreme longevity and precision metrology.
Key Features:
- Smart water consumption monitoring: High-precision measurement using internal sensors.
- Automatic hourly GSM data transmission: Secure telemetry updates to the central billing server.
- Long-life battery operation: Designed for multi-year deployment using industrialgrade lithium cells.
- Remote billing support: Seamlessly integrates with the admin portal for automated invoicing.
- Leak and tamper detection: Continuously monitors for abnormal continuous flow or physical interference.

[ Placeholder: Photograph or Rendered Image of the Product ]

## 3 Safety Information

WARNINGS

- Do not open the enclosure: Breaking the factory seal exposes sensitive internal electronics to the environment.
- Do not immerse the device in water: The device enclosure is not currently certified for submersion. Keep the electronic housing clear of standing water.
- Installation must be performed by qualified personnel: Only authorized Water Board technicians should splice or fit the meter into active plumbing lines.
- The battery must only be replaced by authorized service personnel: Improper handling poses a severe fire risk.
- Do not short-circuit, recharge, or puncture the battery: The internal cell contains highly reactive materials.

Battery Information

- Battery Type: Lithium Thionyl Chloride Battery (Li-SOCl2), Model ER34615M, 3.6 V.
- Disposal: Dispose of depleted batteries strictly according to local environmental and hazardous waste regulations. Do not dispose of in standard municipal waste.

## 4 Package Contents

- 1x Smart Water Meter Unit
- 2x User Guide (Client and Admin)
- 1x Warranty Card

## 5 Product Components

[ Placeholder: Labelled external view diagram ]

- Water Inlet: Threaded connection for incoming supply.
- Water Outlet: Threaded connection for property supply.
- LCD Display: Digital interface for local reading (activates on wake).
- Wake Button: Tactile switch to activate the local display.
- Status LED: Diagnostic indicator for technicians.
- Enclosure: Protective device housing.

## 6 Internal Hardware Overview

The internal circuitry is optimized for ultra-low quiescent current, heavily relying on sleep states, high-efficiency regulators, and isolated power switching for the cellular radio.

### 6.1 PCB Photograph & Layout

Refer to Appendix A and B for full-scale schematics and layouts.

### 6.2 Circuit Breakdown

The main logic board is built using the following datasheet-verified components:
- Microcontroller (MCU - U30): STM32L073CZT6. An ultra-low-power ARM Cortex-M0+ microcontroller. It manages sensor polling, LCD driving, and deep-sleep cycles. It features integrated RTC capabilities essential for the timed transmission architecture.
- High-Current Boost Converter (U21): TPS61023DRLR. A synchronous boost converter capable of delivering up to 3A switching current. Paired with a 2.2uH inductor (L20) and a bank of four 22uF ceramic capacitors (C20-C23), this circuit steps up the ER34615M battery voltage to provide the massive, high-current transient bursts required by the GSM module during transmission.
- Low-Dropout Regulator (LDO - U20): XC6206 Series. A highly precise, extremely low quiescent current LDO regulator (typically 1uA). It continuously steps down and stabilizes the battery voltage to supply clean logic-level power to the MCU and sensors without draining the battery during sleep cycles.
- GSM Load Switching (Q40 & Q41): To prevent the cellular radio from causing parasitic battery drain while idle, power is completely isolated using a high-side load switch. This utilizes an AO3401A P-Channel MOSFET (Q40)—chosen for its low onresistance—driven by an MMBT3904 NPN Transistor (Q41) acting as a logic-level gate driver controlled by the MCU.
- Timing & RTC (OSC30): A dedicated Crystal Oscillator, stabilized by 22pF load capacitors (C30, C31), drives the MCU’s Low-Speed External (LSE) clock to maintain strict hourly wake-up schedules.
- User Interface (SW30): An MJTP1230A SPST tactile switch has been used to reset the MCU.

## 7 Technical Specifications

Parameter | Specification
MCU | STM32L073CZT6 (ARM Cortex-M0+)
LDO Logic Regulator | XC6206 Series
GSM Boost Converter | TPS61023DRLR (3A Switching)
GSM Load Switch | AO3401A (MOSFET) / MMBT3904 (BJT)
Communication | GSM Module
Main Battery | ER34615M Lithium Thionyl Chloride
Battery Voltage | 3.6 V
Flow Sensor | Hall Effect
Transmission Interval | Hourly (Default)
Measurement Unit | Liters

## 8 Installation

1. Shut off water supply: Ensure the main line is completely isolated.
2. Install meter: Fit the meter into the plumbing line.
3. Ensure correct flow direction: Check the directional arrow embossed on the housing.
4. Tighten fittings: Use provided accessories; ensure seals prevent leaks.
5. Verify GSM signal: Press the Wake button to ensure power, and check the dashboard.
6. Activate device: The meter will automatically enter its sleep cycle.

## 9 Device Operation

- Measurement: Internal sensors continuously monitor magnetic rotation, accumulating Liters.
- Hourly Transmission: The RTC wakes the MCU hourly. The MCU signals the MMBT3904 to open the AO3401A MOSFET, supplying power from the TPS61023DRLR boost converter to the GSM module. Once data is sent, the switch is closed.
- Sleep Mode: Between transmissions, the device enters deep sleep, drawing minimal power via the XC6206 LDO.
- Automatic Wake-up: The tactile wake button triggers a hardware interrupt for local reading.

## 10 LED Indicators

LED Status | Meaning
Green (ON) | Normal Operation / Wake cycle active
Red (ON) | Power on

## 11 Maintenance

- Cleaning: Wipe the enclosure with a damp, non-abrasive cloth.
- Visual Inspection: Regularly check housing and fittings for leaks.
- Battery Replacement: The ER34615M Lithium Battery is not user-serviceable. Replacement must be performed by authorized service personnel to ensure electrical safety and correct system operation.

## 12 Troubleshooting

Problem | Possible Cause | Solution
Offline (No Data) | No GSM signal / RF Shielding | Move heavy metal objects away. Verify network.
No display on wake | Battery depleted | Contact service for ER34615M replacement.
Incorrect readings | Sensor issue / Blocked impeller | Contact technical support.
Water leak | Installation fault | Shut off mains, inspect fittings.

## 13 Frequently Asked Questions

Q: How often is data transmitted?
A: The meter connects to the cellular network and updates the dashboard once every hour.

Q: Can I replace the battery myself ?
A: No. To maintain the integrity of the device and ensure safety, replacement must be done by authorized technicians.

Q: What happens if the GSM network is unavailable?
A: The meter stores consumption data locally and transmits the backlog once connection is restored.

## 14 Warranty

Covered by a standard manufacturer’s warranty against defects. Voids: Opening the device enclosure, unauthorized battery replacement, physical damage, freezing, or tampering.

## 15 Regulatory & Safety Information

Designed for educational and research purposes.
(Pending commercial environmental testing and certifications).

## 16 Appendix

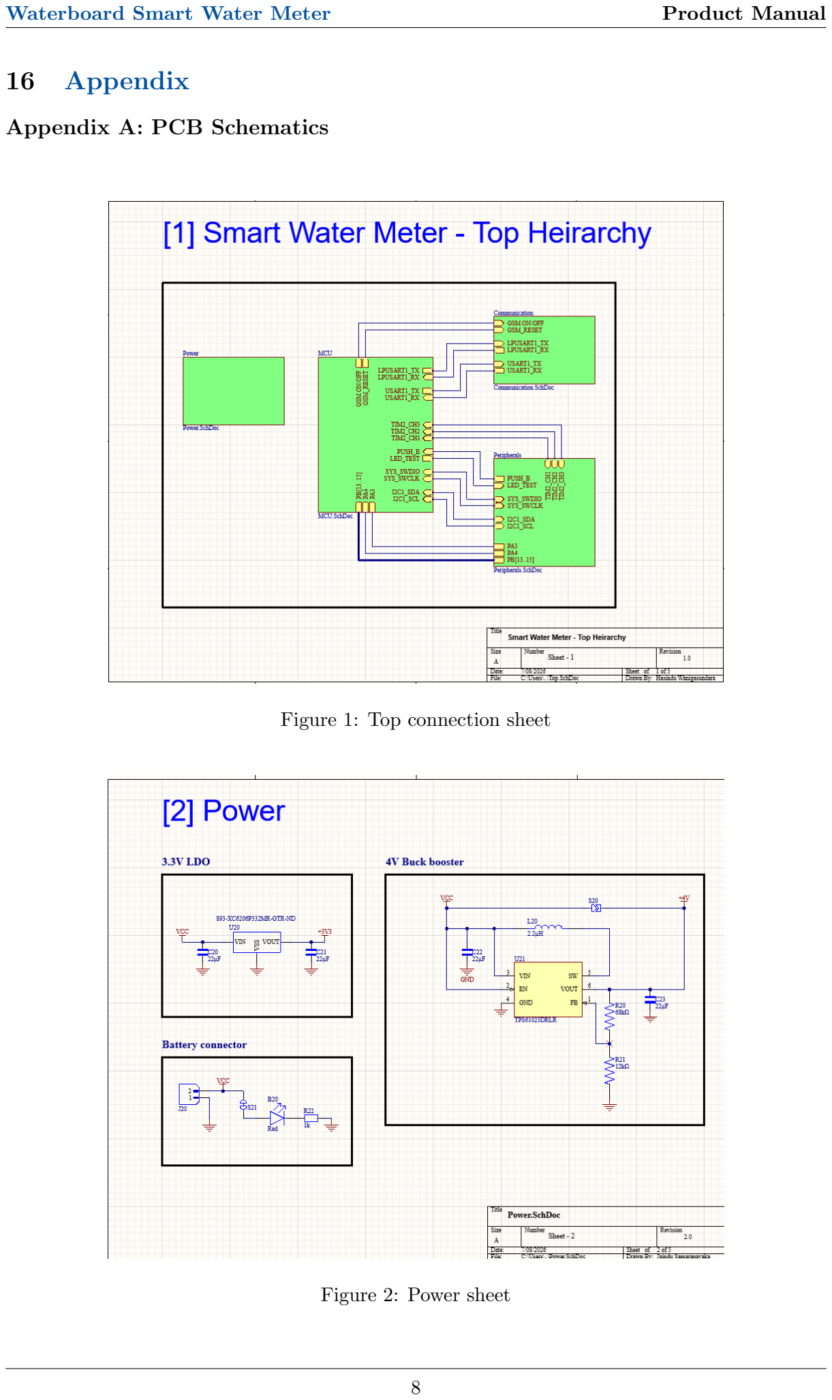
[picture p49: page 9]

Appendix A: PCB Schematics

Figure 1: Top connection sheet

Figure 2: Power sheet

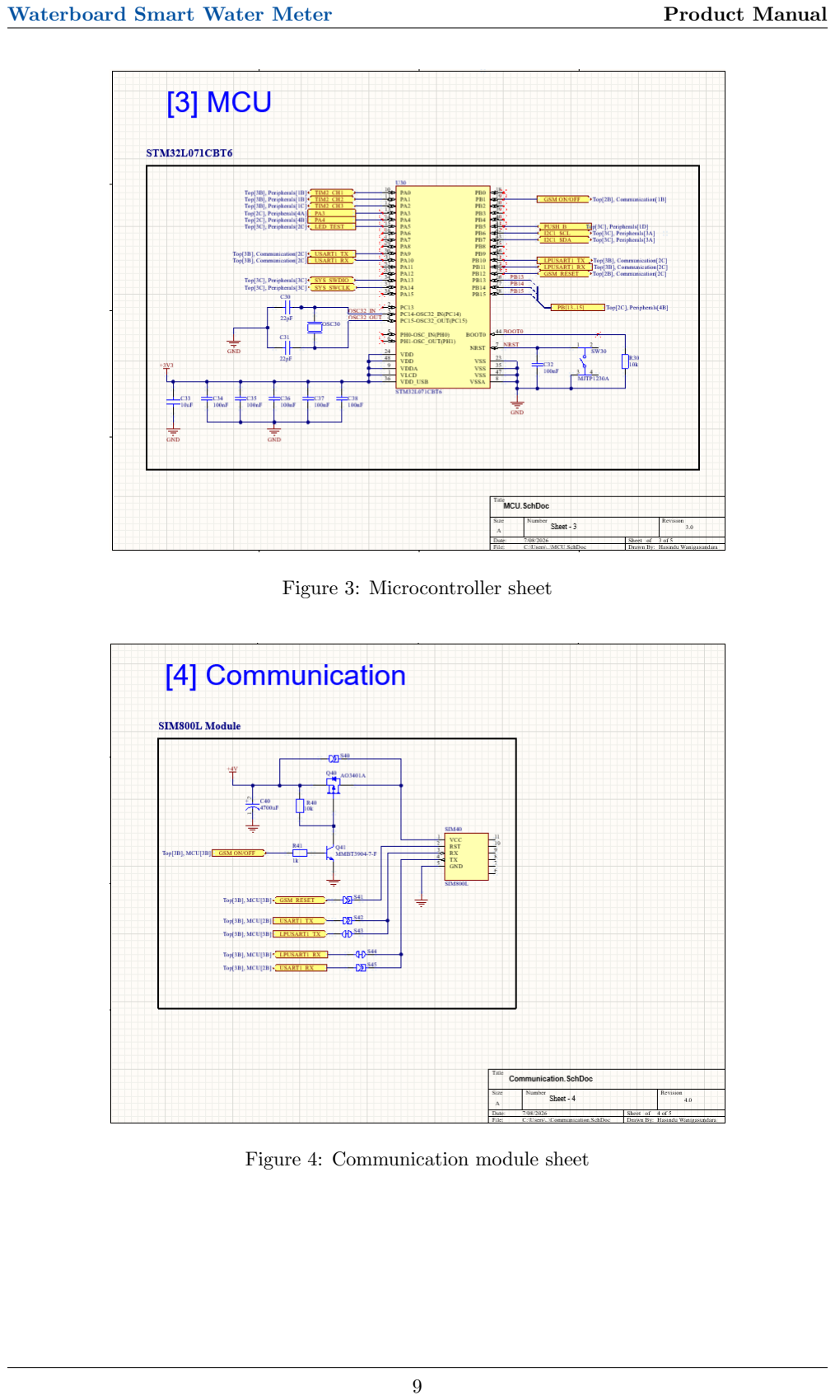
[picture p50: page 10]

Figure 3: Microcontroller sheet

Figure 4: Communication module sheet

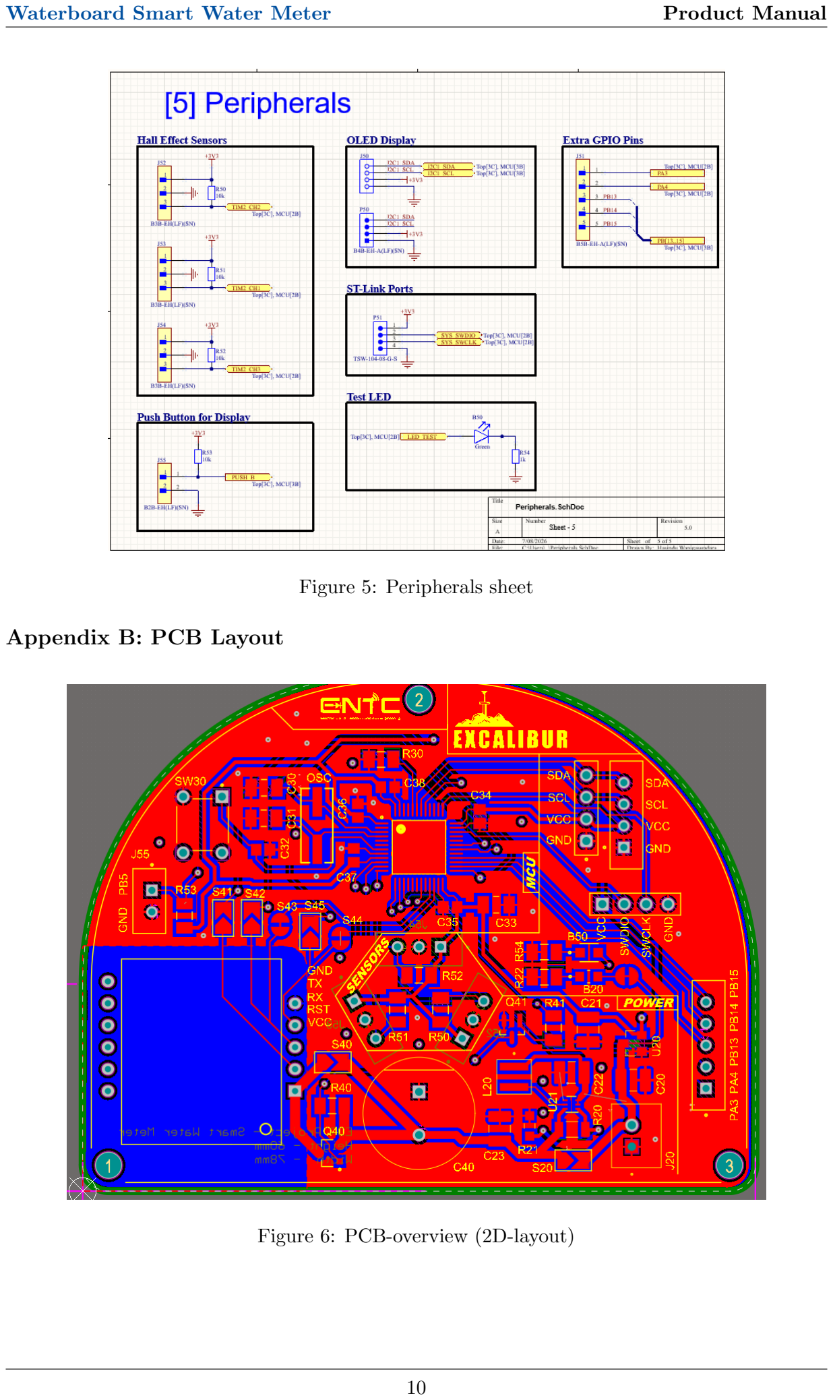
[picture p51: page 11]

Figure 5: Peripherals sheet

Appendix B: PCB Layout

Figure 6: PCB-overview (2D-layout)

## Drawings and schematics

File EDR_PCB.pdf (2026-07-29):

# EDR Project - Semester 4

# Smart Water Meter

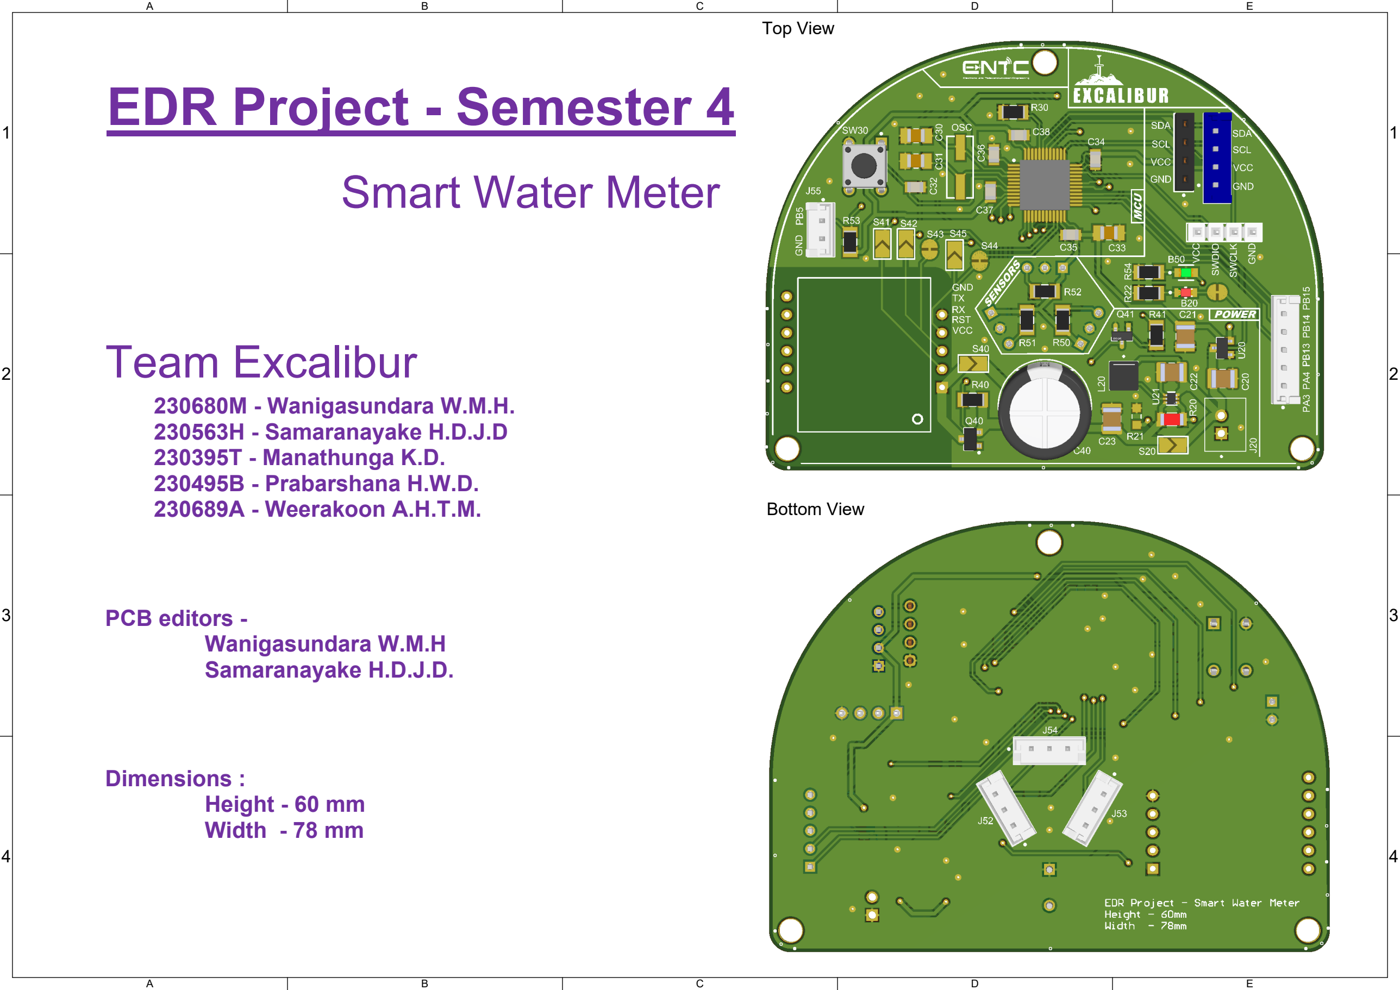
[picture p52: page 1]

A

B

C

D

E

1 | 1
2 | 2
3 | 3
4 | 4

Top View

Bottom View

# Team Excalibur

230680M - Wanigasundara W.M.H.

## 230563H - Samaranayake H.D.J.D

230395T - Manathunga K.D.
230495B - Prabarshana H.W.D. 230689A - Weerakoon A.H.T.M.

## PCB editors -Wanigasundara W.M.H

Samaranayake H.D.J.D.

## Dimensions : Height - 60 mm Width - 78 mm

R30

C30

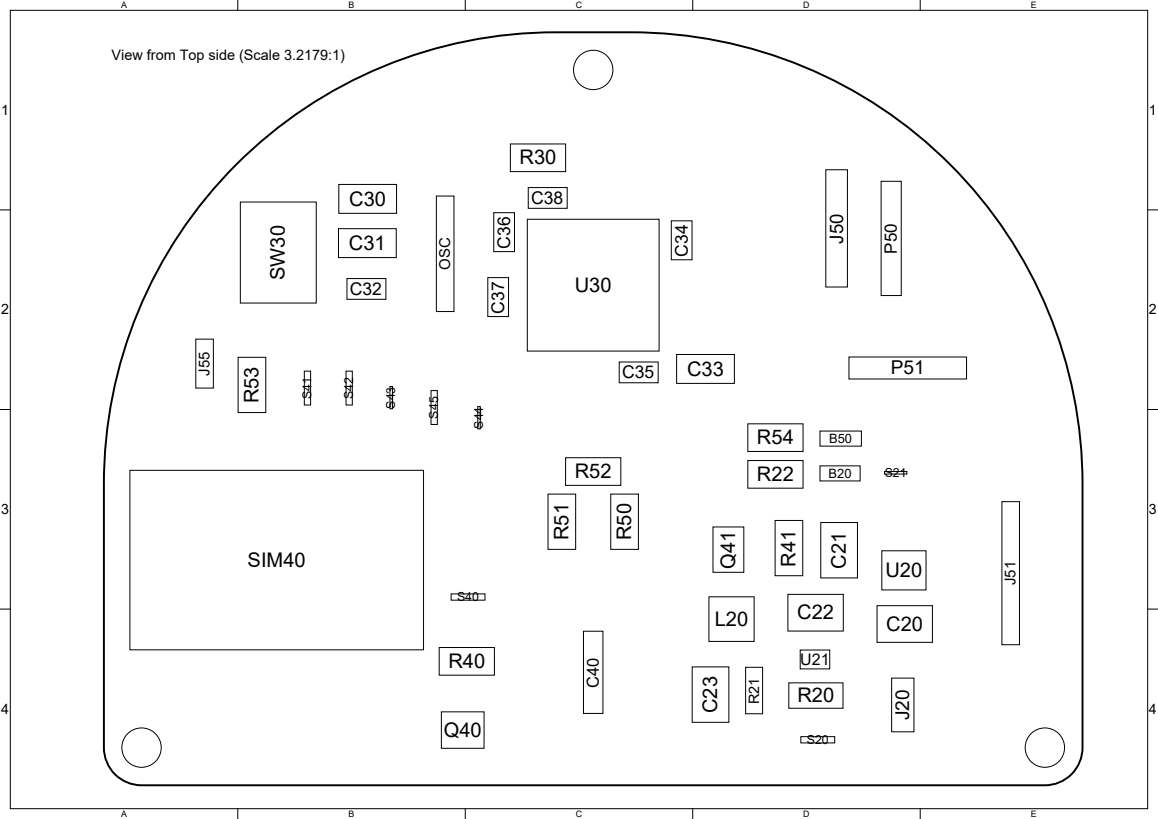
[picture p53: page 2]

View from Top side (Scale 3.2179:1)

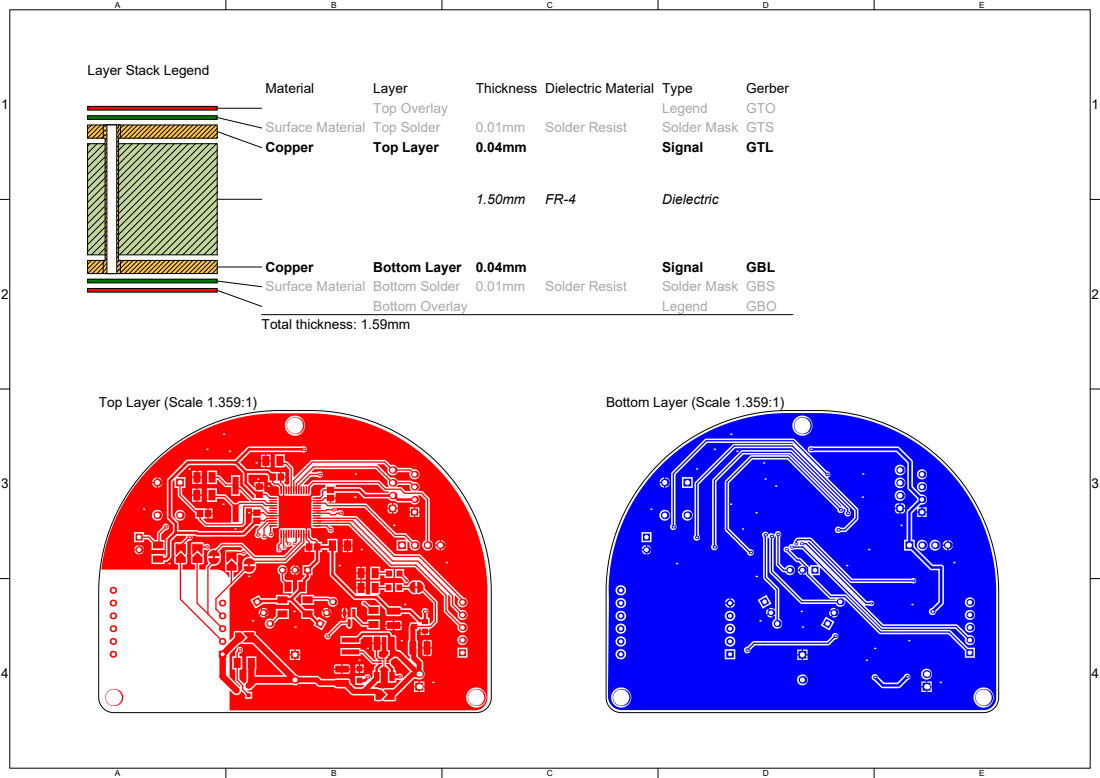
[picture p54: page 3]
Top Layer (Scale 1.359:1); Bottom Layer (Scale 1.359:1); Material; Layer; Thickness Dielectric Material Type; Gerber; Top Overlay; Legend; GTO; Surface Material Top Solder; Solder Resist; Solder Mask GTS; Copper; Top Layer; Signal; GTL; Dielectric; Bottom Layer 0.04mm; GBL; Surface Material Bottom Solder 0.01mm; Solder Mask GBS; Bottom Overlay; GBO; Total thickness: 1.59mm

Layer Stack Legend
